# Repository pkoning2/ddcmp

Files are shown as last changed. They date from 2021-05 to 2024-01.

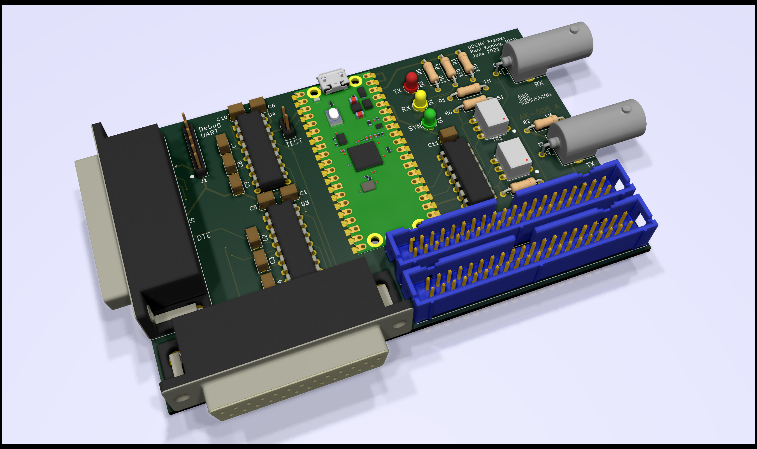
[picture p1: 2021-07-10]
kicad/ddcmp/ddcmp.png

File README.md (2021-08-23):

# DDCMP Framer

This is a DDCMP synchronous link framer, connected to a host with a USB interface.

## Documentation

For detailed documentation, look in the `doc` subdirectory:

1. `api.md` -- programming interface for the framer.
2. `kicad.md` -- instructions for assembling the circuit board.
3. `software.md` -- how to build and load the firmware.
4. `design.md` -- design notes.

## Connections

To use the framer, connect the micro-USB board to a USB port on the computer that will control the framer.

There are a number of choices for connecting the synchronous link to whatever device you want to use it with:

1. To use a synchronous modem or modem eliminator, connect it with a straight through DB-25 cable to the male DB-25 (marked "DTE"), and operate the framer in "rs232_dte" mode.

2. To connect to a DDCMP device such as the DMR-11 using an RS-232 connection, connect its male DB-25 connector with a straight through DB-25 cable to the female DB-25 (marked "DCE") on the framer, and operate the framer in "rs232_dce" mode.  In this mode the framer supplies the bit clocks; you specify the desiredd data rate as one of the start command parameters.

3. If you have a device such as a DMR-11 that has a line card which is meant to connect to a BC55 bulkhead panel via a 40-pin ribbon cable, but you don't have or do not want to use a bulkhead panel, connect the line unit with 40 pin ribbon cable to the 40-pin header J8 (marked "To LU").  You can use either RS-232 (with bit clock generated by the framer) or integral modem operation using this connection.

4. If you want to connect the framer to a BC55 bulkhead panel (RS-232 or integral modem), connect the BC55 with a 40-pin ribbon cable to the 40-pin header J7.  Do not install termination resistors on the integral modem panel (BC55A); for details, refer to `doc/kicad.md`.

5. You can connect integral modem coaxial cables to BNC connectors J2 (incoming data) and J3 (outgoing data).  Note that DEC specifies triax cable (two shields) but those connectors are expensive so here we just use BNC connectors, which should be fine so long as you're not operating in an extremely noisy environment.  Do not install terminating resistors at the framer end, they are built in to the board.

## Indicator lights

There are three indicator lights on the framer board, as well as an LED on the Raspberry Pico board itself.  They are:

1. Pico board LED: "on" indicator.  It lights up when the framer is started with a successful start command, and off when the framer is stopped.

2. "SYN" indicator: byte sync status.  This lights up when the framer receiver has completed byte synchronization, having received four or more consecutive SYN bytes (hex 96).  SYN status remains set unless the DDCMP state machine restarts sync search; it will do so if a header CRC error occurs.  If the light does not come on, this may indicate no received signal, or (for integral modem mode) speed mismatch exceeding the 10% receive rate tolerance.  If the SYN indicator flashes frequently, this may indicate poor signal quality, or (for integral modem mode) a speed mismatch right at the limit of what the device can handle.  Note that the weak signal capability of the integral modem depends on the transformers used; refer to `doc/kicad.md` for details.

3. "RX" indicator: flashes when a frame is received (either successfully or with an error).

4. "TX" indicator: flashes when a frame is transmitted.

The RX and TX LEDs have pulse stretchers, so the light flashes are clearly visible even at low packet rates.

The RX and TX LEDs flash once when a framer start command is successfully executed.

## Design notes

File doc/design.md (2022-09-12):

# Some design details of the DDCMP Framer

The framer takes advantage of a number of features provided by the Raspberry Pico RP2040 chip:

1. High speed programmable I/O state machine engines
2. Dual ARM core
3. USB support

For details, refer to the [RP2040 datasheet](https://datasheets.raspberrypi.org/rp2040/rp2040-datasheet.pdf "Data sheet").

# Receive processing

Synchronous DDCMP reception consists of a number of stages:

1. Demodulation (integral modem case)
2. Byte framing
3. Packet framing

## Demodulation

In the RS-232 DTE case, demodulation (which includes clock and bit data recovery) is done by the modem.  In the RS-232 DCE case, these steps do not really appear since the clock is generated locally and the bits appear as-is on the receive data pin.

For the integral modem, the framer does the demodulation of the FM modulated signal.  (For details, refer to the DMC11 Synchronous Line Unit Maintenance Manual, EK-DMCLU-TM-002.)   One of the PIO state machines handles clock and data recovery.  The approach is vaguely like the classic technique for UART receive; the state machine runs at 16x the nominal data rate, looking for the edge at the start of the bit cell.  It then waits for 3/4 of the bit time, and samples the input state.  If it is the same as at the start of the bit cell, that is a one bit, otherwise it is a zero bit.  The resulting data bit and a bit strobe signal (PIO IRQ signal) are generated by the demodulator state machine and will be used by the byte framing state machine.

## Byte framing

This consists of two stages: sync search, and data byte processing once in sync.  The input to the byte framing PIO state machine is the received data bit stream and clock.  The clock is an input pin for RS-232 DTE mode, the locally generated clock for RS-232 DCE mode, or the recovered bit clock for integral modem mode.

Initially the byte framing state machine is in sync search mode.  In that mode it shifts bits into a 32 bit register, and after each bit, compares the result against 4 SYN bytes (0x96969696).  Note that ideally it would be best to do a 16-bit compare against 2 SYN bytes, but the hardware does not support that and given that other DDCMP devices normally send around 8 SYN bytes before frames, requiring 4 for synchronization is acceptable.  When a match is seen, we have byte sync and the sync search mode is exited.  At this point the SYN LED is turned on.

When synchronized, the byte framing state machine continues to shift in bits to the input register, and every 32 bits pushes the result to the receive FIFO.  That FIFO is processed by the ARM (core 1), which will see properly framed bytes 4 at a time.

To go back to sync search state, for example to recover from a header CRC error or invalid start of header byte, the ARM core will force the byte framing state machine back to its starting address, which puts it back in sync search state.

## Packet framing

Packet framing is done in the ARM CPU since it is too complex for the PIO state machines.  Because of the real time requirements, core 1 is dedicated to this task; it runs in a tight loop receiving bytes 4 at a time from the byte framing PIO state machine through its receive FIFO.

The packet framer basically implements the DDCMP packet format recognition state machine seen in many other implementations of DDCMP.  It skips leading SYN bytes, then expects a valid start of frame byte (ENQ, SOH, or DLE) followed by 5 more header bytes and a correct 2 byte CRC-16 header CRC.  If the first non-SYN byte is not valid, the packet framer resets the byte framer state machine to sync search mode and goes back to looking for a valid frame start.

If the first byte is a valid start of frame, the framer examines the next entry in the receive buffer ring.  If it is in use, we have a no-buffers condition, which is counted as an error and sync search mode is entered to look for the next frame.  Otherwise, the framer begins to store arriving bytes into that buffer and accumulates the (header) CRC.  After 8 bytes, it verifies the CRC; if it is non-zero, the frame is completed with header CRC error status and sync search is entered.  

If the header CRC is good and the frame is a control frame (ENQ first byte), the buffer is completed as a good frame, and the framer goes back to look for the next frame.  Note that we do not do sync search in this case since the link is currently synchronized.  Other frame types are data; if so, the length field is extracted from the received header.  If it is invalid (zero or greater than 1488), this is counted as a length error and sync search is started.  Otherwise, the framer accumulates the next (length + 2) bytes, which are the frame payload and data CRC.

Once the data and data CRC have been received and buffered, the framer checks for zero CRC.  If so, the frame is marked as complete and good; otherwise, it is marked as commplete with data CRC error.  In either case, the framer goes back to look for another frame.  Unlike header CRC errors, data CRC errors do not trigger sync search.

# Transmit processing

Similar to receive processing, transmit processing for synchronous DDCMP consists of several parts:

1. Frame construction
2. Bit stream generation
3. Modulation

## Frame construction

The connected host supplies complete DDCMP frames to the framer except that the CRC fields are omitted.  The host request handler (in ARM CPU 0) copies the frame to be transmitted into the next transmit ring buffer, if free.  As part of the copy, the CRC is calculated and inserted after the header and, if applicable, the data.  After the end of frame a DEL byte (0xff) is inserted, this is as specified in the DDCMP spec to strengthen the CRC in case a bit is lost or inserted.

Frames are sent to the bit handling state machines using DMA, with the state machine FIFO is set to 8 bits wide.  Also, the transmit ring buffer contains 8 SYN bytes before the frame data area, which will be the sync pattern sent before each frame.  Currently there is no support for sending short sync sequences when permitted, that would only be an optimization and for many cases isn't all that interesting.  Nor is there support for abutting frames, which similarly is only an optimization and the rules are quite complex and involve DDCMP state information not known to the framer.

The transmit FIFO length is controlled by a conditional compile, TX8 which is on by default.  If off, 32 bit FIFO size is used and transmits are padded to 4 byte multiples.  Testing shows that this is not needed for supported speeds; we do see occasional CRC errors in BIST runs (due to FIFO underrun causing SYN bytes to be inserted in mid-packet) but only at 10 Mb/s.  All speeds that work for external connections, including non-standard extra fast speeds (2.5 or 5 Mb/s) work cleanly without underrun at 8 bit FIFO size.

Once the complete frame has been built, the buffer is marked as filled.  If DMA is not currently in progress, DMA of the new buffer is started by submitting its start address (address of the leading SYN sequence) and length to the DMA engine.  If DMA is in progress, this new buffer will be handled by the DMA completion interrupt handler when the DMA for the preceding buffer finishes.

## Bit stream generation and modulation

For RS-232 mode, the output bit stream is simply the sequence of bits (LSB first) from the transmitted packet.  The transmit handler for these modes picks up words from the output FIFO and shifts them a bit at a time to the transmit data pin.  For DTE mode, the shifting happens on the rising edge of the transmit clock input.  For DCE mode, the state machine runs at 4x the required data rate and it shifts output bits and generates the clock signal in a four-instruction loop.

For integral modem mode, the output signal is an FM modulated signal representing the bit stream, with an edge at the beginning of each bit cell and a second edge in the middle if the transmitted bit is a zero.  The PIO state machine program for this mode fetches 32-bit words from the FIFO, then shifts out one bit at a time and generates the correct waveform based on whether the bit is one or zero.  It runs at 4x the required data rate.  Note that for the integral modem case there is no connection between receive and transmit clocks, though the nominal values are expected to match.  The data rates can be set to different values, but this is only intended as a test tool to verify that the receive demodulation can handle bit clocks that are moderately (up to 10% is the DEC specification) out of tolerance.

# Modem control

The framer is designed for full duplex operation with very limited modem control.

In RS-232 using the DTE connection, DTR and RTS are set when the framer is turned on.  Modem control signals from the modem (DSR, CTS, RI, CD) are ignored.

In RS-232 using the DCE connection, DSR, CTS, and CD are set when the framer is turned on, and RI is off.  Modem control signals from the device (DTR, RTS) are ignored.

In integral modem mode, transmit carrier is sent as soon as the framer is turned on.  The line unit startup sequence is sent (see section 4.3.11.3 of the DMC-11 line unit maintenance manual), followed by the idle line state (SYN bytes) until the host starts sending DDCMP frames.

The RS-232 hardware does not support half-duplex or full modem control operation, mostly because the transceivers used don't have enough drivers and receivers to handle all the modem control pins explicitly.

The integral modem hardware has the transmit driver enable under firmware control, which means that it is probably possible to implement half duplex or multipoint operation, where the carrier has to be turned off when the station is not actively transmitting.  There is no support for this in the firmware, though.

# Host interface handling

The host interface uses the TinyUSB open source library, in device mode configured as an Ethernet device.  Some of the bits are adapted from the TinyUSB web server example, but note that the DDCMP Framer uses raw Ethernet, not IP.

The main loop, running in ARM CPU 0, polls the USB for outgoing Ethernet frames and the received packet ring (from CPU 1) for incoming DDCMP frames to be sent to the host.

The messages exchanged between host and framer are constructed as standard Ethernet frames, except that short frames are not padded (framer to host) or required to be padded (host to framer).  Refer to the API documentation in api.md for details on the encoding of the frames.

## Outbound frame processing (host to framer)

The framer checks the Ethernet protocol type field for the value 60-06 (the DEC reserved value for "customer use").  Frames with other protocol types are ignored.  Some will appear because operating services like DHCP or other configuration mechanisms may send IP frames on any interface that shows up.

If a framer type frame is seen, the first byte of the data is examined to see if it is a command or a frame to be transmitted.  Transmit frames are recognized by the fact that they start with one of the DDCMP frame start values EQN (005), SOH (201) or DLE (220).  Command use a DC1 (021) byte instead.  Any other first byte is an error.

Data frames are copied into a transmit buffer with CRC generated during the copy, then transmitted as described above.

Invalid requests including invalid transmits (such as bad frame lengths) are reported by the framer generating a status message to the host, in which the last_cmd_sts field is set to a non-zero value indicating the error.  Apart from that reporting, the request that encountered the error is ignored.

Commands have a command code in the second byte.  Defined commands are status request, off, on, and raw transmit.  Raw transmit is a test tool for diagnostics, it is not expected to be used in normal operation.  On and raw transmit requests have data following the command code, see the API document for details.

All commands except for a valid raw transmit generate a status reply.  Valid raw transmits are handled (the data is transmitted exactly as supplied, without any leading SYN, CRC handling, or trailing bytes added) with no status reply.

### "On" command

The command to start the framer includes additional data specifying the operating mode and data rate.  Refer to the API spec for details.

Command processing sets all the Pico pins to the proper operating setting, loads the appropriate programs into the PIO state machines, configures them, and starts them.  It also starts CPU 1 if that has not already been done (it is done only once per power up since CPU 1 can't be stopped after having been started).

Two of the PIO state machines control the receive and transmit activity LEDs, providing "pulse stretching" so the light flashes are bright enough to be visible if traffic is sporadic.  They flash once when started, so the execution of the "On" command will light the "active" LED (on the Pico board) and flash the RX and TX LEDs once.  The SYN LED will be off until a valid signal is received and byte sync is established.

## Inbound frame processing (framer to host)

In the main loop the framer looks for things to send to the host.  There are two cases: status, and received data.  Status takes precedence.

At any time when status needs to be reported, the `send_status` flag is set.  If it seen set in the main loop, the status buffer is sent to the host and the flag cleared.

Otherwise, if the next buffer in the receive ring is not free, it is sent to the host and marked free.

The first two bytes in all inbound frames are the receive status, which is 0 for good frames and non-zero for various error cases such as header CRC error.  (Refer to the API spec for details.)  Status frames always have 0 receive status.

# BIST

Built-in self test is intended mostly as a simple test to verify a newly built framer is working correctly.  In BIST mode, the framer continuously transmits 500 byte frames (MOP mode frames) containing an incrementing sequence number followed by a mixed data pattern.  Any received frames are counted but otherwise ignored.  Transmit requests from the host are silently ignored, but status requests and stop command are honored.  Every 1000 transmits, a status message is generated.

There are two ways to invoke BIST:

## Power up BIST

If GPIO pin 2 is grounded at framer power up (for example, by installing a jumper on 2-pin header J4, labeled "TEST"), this forces BIST, integral modem, internal loopback, 1 Mbps.  The USB interface is still active in this mode so the host can monitor BIST progress from the periodic status frames, and can stop the test by sending an Off command.

## BIST mode in Framer On commands

The host can request BIST mode as part of an "On" command.  This allows BIST mode to be run (i.e., the traffic generator and receive packet ignore functions) with other operating modes such as RS-232 and external loopback, or no loopback at all.  Several of the tests in the framer test suite in PyDECnet use this option.

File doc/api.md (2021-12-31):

# DDCMP Framer application interface specification

The framer appears to the host as an Ethernet interface.  The interface hardware address starts with aa-00-03 (an unused OUI once assigned to DEC and then rendered obsolete by IEEE 802 -- see `ether-i.pdf`).  The next 23 bits of the interface address are random, derived from the Raspberry Pico unique board ID, and the low order bit is 0 so the interface address is even.  The framer appears as an Ethernet device attached to that interface; its address is one larger than the interface address. 

Communication with the framer uses raw Ethenet packets with protocol type is 60-06 (DEC protocol type assigned to "Customer use").  Following the protocol type is a payload length field, 2 bytes little endian, following the common pattern of many Digital protocols (like DECnet).  This allows the frames to be padded to the minimum Ethernet size; USB does not require this but SIMH does.  Note that padding has a clearly visible performance impact for some workloads (lots of small frames arriving quickly); if this is an issue you may want to experiment with having it turned off.  Note that the framer does not examine the Ethernet address fields of message sent to it; so long as the protocol type is 60-06, it will process the frame.  

The payload of these Ethernet packets is either a DDCMP frame, or a command/status packet.  The encoding is slightly different for inbound (received data to host) vs. outbound (transmitted data from host).

Outbound payloads are simply DDCMP frames as encoded on the wire, except that the CRC values are generated by the framer.  The CRC at the end may simply be omitted (so a DDCMP control frame need only be 6 bytes).  The header CRC field of data frames is present but not used, so the data begins the usual 8 bytes after the start of the frame.  The framer supplies header and (if applicable) data CRC fields, as well as leading SYN and trailing DEL bytes.  

Inbound payloads begin with a 2-byte receive status value, followed by the received DDCMP frame exactly as received, including the CRC fields.  Note that the framer implements CRC checking; the host normally would not look at the CRC bytes but simply use the status value to learn whether the packet is good or bad.

In either direction, we pad frames to the minimum frame length of Ethernet.  USB emulated Ethernet NIC does not appear to object to undersized frames, but some applications (like SIMH) assume that the Ethernet minimum should be enforced.  Since we limit framer packets to standard Ethernet size, the largest DDCMP data length supported is 1486.

Command/status packets begin with 021 (DC1) which is not a DDCMP frame start value.  Outbound they carry commands to the adapter; inbound they carry status and counters.  Note that the inbound status packet is preceded by a receive status word, as always; for status packets the receive status is always zero (OK).

Receive status word values:

0: good frame

1: Header CRC error

2: Data CRC error

3: Frame too long (if so, the entire data field is absent)

4: Loss of carrier or bit clock in the middle of a frame (the buffer will contain the portion of the frame that was received)

Command packets start with 021.  The next byte is the command:

0: status request

1: start

2: stop

3: send raw data

Status, start, and stop commands produce a status packet in reply (the status request simply is a "no state change" command).  "Send raw data" commands do not for valid requests, but if the command is rejected for any reason a status is generated to show this. For "send raw data", the data to be sent is the remainder of the command packet, starting immediately ater the command byte.  

For start, configuration settings follow:

Mode and flag bits (2 bytes).  Mode is the bottom 2 bits:

0: RS-232 DTE mode (bit clocks supplied by the connected modem)

1: Integral modem

2: RS-232 DCE mode (bit clock generated by framer)

Flags:

Bit 2: Internal loopback.  If mode is supplied as 0, it is forced to 2.

Bit 3: Built-in selftest.  In this mode, transmit requests are ignored and
received data is counted but not delivered.  The framer internally
generates a stream of DDCMP messages (500 bytes long) to exercise the
transmit and receive data paths.  Status requests still work so
progress can be monitored via status requests, and a stop command will
terminate the test.

Bit 4: Split speed.  This applies only to the integral modem case.  If set, the transmit speed is taken from the txspeed field rather than the speed field.  This is a test function that allows verifying the correct operation of receive data recovery when the sending end data rate is out of spec.

Bit 5: DMC mode (DDCMP V3.03).  Modifies the frame generation rules to match what the DMC11 needs.  See the DMC11 Microprocessor manual, appendix I, for details.

Bit 6: Raw waveform mode.  Valid with integral modem only.  In this mode, the modulator part of the integral modem handling is bypassed.  Only the "raw transmit" command can be be used; regular transmit is rejected.  Cannot be combined with BIST mode.  The raw transmit buffer is interpreted as one bit per modulation time slot (two bits per data element) directly representing the waveform to be transmitted.  This is a test mode, intended for verifying receive clock/data recovery and the handling of loss of carrier.  See the "test_framer" test suite for examples.

Speed: (4 bytes):

This specifies the bit rate in bits per second.  For RS-232 DCE mode, it is the frequency of the receive and transmit clock signals.  For integral modem, it is the transmit speed and the nominal receive speed; actual receive clocking is from the incoming data, which must match the specified rate +/- 6%.  Speed is not applicable for RS-232 DTE mode, in which the bit clocking is entirely under control of the modem.  Note that RS-232 is not officially specified for high speeds; it works well at 56 kbps with short cables, and can probably be made to work at 250 kbps, but it is unlikely to run at 1 Mbps since the required rise/fall times are too slow for that.  Standard integral modem speeds go as high as 1 Mbps; the adapter can go faster but standard DEC hardware does not; also, at some higher speeds the quantization error of the PIO clock divider becomes a problem and receive data recovery no longer works.

Transmit speed (4 bytes):

This is the transmit data rate, if the "split speed" bit is set in `mflags`.

Status packet starts with 021 (after the usual 2 byte payload length and receive status fields), followed by state and counter data:

* state (1 byte): flags, bit 0 = on (active), bit 1 = in-sync, bit 2 = bit clock ok
* mode and flags (2 bytes): as described above for the Start command
* maximum frame payload: 1486 -- information for the host software
* speed (4 bytes): as described above.  Not used for RS-232 DTE mode.
* transmit speed (4 bytes): as described above.  
* Counters -- all are 4 bytes and wrap on overflow:
* received good frames
* transmitted frames
* received good bytes
* transmitted bytes
* header crc errors
* data crc errors
* frame too long errors
* buffer unavailable errors
* Additional status:
* last command status (4 bytes), 0 for good, non-zero for various errors
* measured data rate (4 bytes), in bits per second
* framer firmware version (null-terminated ASCII string)

Status messages are generated:
1. At device powerup.
2. In response to any command.
3. In response to a transmit or raw-transmit request that has invalid parameters.
4. When the in-sync status changes (sync acquired or sync lost).
5. In BIST mode, after every 1000 transmitted frames.

Note that the measured data rate for the integral modem case is an approximation since it operates by measuring the edge timing of the received waveform.  The calculation assumes that the received data is half ones and half zeroes, which is the case for an idle line (SYN bytes are half and half).  If the line is actively carrying data and that data has a different bit density the measured line rate will be inaccurate; in particular for all zeroes it will be 33% higher than the true value.  The intent of this data item is to allow checking the data rate of a connected device whose clock may be off spec or unknown, allowing the framer to be configured with a matching data rate for reliable operation.

Last command status values are:

0: OK (command accepted)

1: Command message too short (must be at least 2 bytes for status or stop, at least 8 bytes for start).

2: Unrecognized command code (byte after the 0x11 command marker)

3: Start command issued when the device is already started

4: Speed out of range.  Supported speeds are 500 to 1,000,000 bits per second.

5: Bad transmit length.  For regular transmits, this means a control frame (starts with 0x05) less than 6 bytes long, or a data frame (starts with 0x81 or 0x90) with length in the header either 0 or greater than 1486, or not enough data in the Ethernet packet for the length given in the header.  For raw transmit, more than 1486 bytes.

6: Transmit request when the framer is stopped.

7: Invalid combination of mode bits in start command: RAW_WAVEFORM mode used with RS232 or BIST.

8: (Regular) transmit request while RAW_WAVEFORM mode is in effect.

Note that transmit attempts in BIST mode are not errors; they are simply ignored.

## Diagnostics

### Built-in self test

If the framer is powered up with a jumper installed on J4 (marked "TEST"), it enters BIST mode in integral modem mode, internal loopback, 1 Mb/s.  Note that internal loopback of any kind is not dependent on the transceiver hardware, so it works even if the corresponding external connection option is not installed on the board.  In BIST mode the device continuously sends 500 byte test data frames, which are received and counted but not otherwise processed.  Every 1000 transmitted frames a status message is generated and sent to the host, which can be used to monitor the progress of the BIST.  BIST mode continues until the framer is powered down or until a "stop" command is issued.

BIST mode can also requested by setting bit 3 in the mode/flags field of a "Start" command.  In this case, the operating mode and loopback or not are selected by the other bits in the field.  So, for example, if a loopback connector is installed on the RS-232 DCE connector, a test including the RS-232 transceivers can be done by requesting RS-232 DCE mode, a suitable speed (250,000 should work) and BIST.

## Device validation and diagnostic test suite

The DECnet/Python package, in the `tests` directory, contains a set of framer tests in `test_framer.py`.  These can be invoked in the usual way, either the full set or any desired specific tests or test classes.  Refer to the Python library manual, "unittest" module, for details.  Some of the tests require loopback connectors to be installed, and some that use RS-232 DTE mode also require a clock source such as a modem eliminator to be attached to the DTE connector.  If this is not done those tests will fail with messages indicating the reason is a missing loopback connector or clock source.

The full set of framer tests require about 3.5 minutes to run.

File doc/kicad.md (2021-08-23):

# DDCMP Framer

The `kicad/ddcmp` subdirectory contains the design files for the DDCMP framer circuit board (AK-005 A), which you can inspect or modify using the open source KiCAD package.

## Creating the circuit board

There are three ways to get a circuit board.
1. From the shared designs section of the OSHPark PCB fabricator website, in [this link](https://oshpark.com/shared_projects/buAWT8Hy "DDCMP Framer").
2. From any PCB fabricator that accepts KiCAD board files (such as OSHPark).
3. From any PCB fabricator that doesn't, by generating the standard *Gerber* files.

If you want to use a fabricator that needs Gerber files, open the `ddcmp.kicad_pcb` file using KiCAD (specifically the *Pcbnew* application) and use the File->Plot menu option to generate them.  You'll want to review the detailed instructions from the fabricator to confirm settings, file name rules, etc.

## Schematic

The board schematic is in `ddcmp.sch` (which is the top level of a hierarchical design pointing to three additional `*.sch` files).  You won't need this to create the board, but you can review this if you are interested, or if you want to modify the design.

## Assembly

The design is a simple circuit board; nearly all components are through-hole.  The one exception is the pair of Min-Circuits transformers, which are surface mount, but with 0.1 inch lead pitch so they do not create any problem.  If you have experience building small electronic kits it should not create any problems.  If you do not, you may want to seek out some help since this is not a "Heathkit" style kit with detailed instructions or tutorials.

## Parts list

Here are all the parts in the design, with schematic reference (also on the board silk screen labeling), value or device type, description, along with manufacturer name and Digikey part number.  The Digikey numbers are just by way of illustration.  Capacitors and resistors are generic, you can replace them by similar devices from other suppliers so long as they fit in the available space.  The capacitors  are small ceramic devices with 0.1 inch lead spacing; the resistors are standard 1/4 watt parts. 

| Ref | Value | Description | Manufacturer | Digikey part # |
| --- | ----- | --- | --- | --- |
| C1 | 0.1uF | Ceramic capacitor | Kemet | 399-14010-1-ND |
| C2 | 0.1uF | Ceramic capacitor | Kemet | 399-14010-1-ND |
| C3 | 0.1uF | Ceramic capacitor | Kemet | 399-14010-1-ND |
| C4 | 0.1uF | Ceramic capacitor | Kemet | 399-14010-1-ND |
| C5 | 0.1uF | Ceramic capacitor | Kemet | 399-14010-1-ND |
| C6 | 0.1uF | Ceramic capacitor | Kemet | 399-14010-1-ND |
| C7 | 0.1uF | Ceramic capacitor | Kemet | 399-14010-1-ND |
| C8 | 0.1uF | Ceramic capacitor | Kemet | 399-14010-1-ND |
| C9 | 0.1uF | Ceramic capacitor | Kemet | 399-14010-1-ND |
| C10 | 0.1uF | Ceramic capacitor | Kemet | 399-14010-1-ND |
| C11 | 0.1uF | Ceramic capacitor | Kemet | 399-14010-1-ND |
| D1 | SYN | 3 mm green LED | SunLED | 1497-1490-ND |
| D2 | RX | 3 mm yellow LED | SunLED | 1497-1492-ND |
| D3 | TX | 3 mm red LED | SunLED | 1497-1491-ND |
| J1 | UART | 6-pin header | Harwin Inc. | 952-2269-ND |
| J2 | RX | BNC connector | Molex | WM20430-ND |
| J3 | TX | BNC connector | Molex | WM20430-ND |
| J4 | TEST | 2-pin header | Harwin Inc. | 952-2261-ND |
| J5 | DTE | DB25 male connector | Amphenol ICC | L717SDB25P1ACH4F-ND |
| J6 | DCE | DB25 female connector | Amphenol ICC | L77SDB25S1ACH3R-ND |
| J7 | To BC55 | "Berg" 40 pin connector | Amphenol ICC | 609-1779-ND |
| J8 | To LU | "Berg" 40 pin connector | Amphenol ICC | 609-1779-ND |
| R1 | 1M | Carbon film resistor | Yageo | 1.0MQBK-ND |
| R2 | 1M | Carbon film resistor | Yageo | 1.0MQBK-ND |
| R3 | 150 | Carbon film resistor | Yageo | 150QBK-ND |
| R4 | 150 | Carbon film resistor | Yageo | 150QBK-ND |
| R5 | 150 | Carbon film resistor | Yageo | 150QBK-ND |
| R6 | 51 | Carbon film resistor | Yageo | 51QBK-ND |
| R7 | 51 | Carbon film resistor | Yageo | 51QBK-ND |
| TR1 | TT1-6-X65+ | Transformer | Mini-Circuits |  |
| TR2 | TT1-6-X65+ | Transformer | Mini-Circuits |  |
| U1 | Pico | Raspberry Pico | Raspberry Pi | 2648-SC0915CT-ND  |
| U2 | max3491ecpd | RS-422 transceiver | Maxim | MAX3491CPD+-ND |
| U3 | MAX3222 | RS-232 transceiver | Maxim | MAX3222ECPN+-ND |
| U4 | MAX3222 | RS-232 transceiver | Maxim | MAX3222ECPN+-ND |

If you want to use Digikey as your supplier, the saved BOM is available [there](https://www.digikey.com/short/h1mqd0dm "Digikey BOM").  Note that TR1 and TR2 are not in that BOM since Digikey does not have these; you can order them directly from Mini-Circuits.

### Optional components

Apart from U1 (the processor) almost all the parts are optional; install them or not depending on which features you are interested in.  When in doubt, consult the schematic to see what each part does.

The options are:

1. RS-232 support: C1-C10, J4, J5, U3, U4.
2. RS-232 DTE support: J5.
3. RS-232 DCE support: J4.
4. Activity lights: omit D1, D2, and/or D3 with their associated resistors R3, R4, and/or R5 if you do not want the SYN, RX, and/or TX indicators.
5. Integral modem support: C11, J2, J3, R1, R2, R6, R7, TR1, TR2, U2.
6. Integral modem direct coax connection: J2, J3.
7. DEC BC55 bulkhead connection support: J7.
8. Connection to DMR/DMP/DMV line unit, or DMC RS-232 line unit: J8.
9. Debug UART connection: J1.
10. Easy access to built-in selftest feature: J4.

The BOM and schematic shows a green LED for the SYN indicator, yellow for RX, and red for TX.  You can use other combinations of red, yellow, and/or green if you prefer.  Note that blue or white LEDs have too high a forward voltage drop to be used here since the output pins are 3 volt outputs.

### Transformer alternatives

The listed part for TR1 and TR2 is the Mini-Circuits TT1-6-X65, which is a 6 pin DIP (through-hole) part.  It doesn't appear in the Digikey catalog, but it can be obtained directly from Mini-Circuits.

If you have trouble getting this part, several other Mini-Circuits transformers could be used instead.  The alternatives are all surface mount parts; the PCB footprint is designed to handle either the surface mount or the DIP part.

#### Tested alternatives

1. Mini-Circuits ADT1-6T+ (Digikey 3157-ADT1-6T+CT-ND).  This one has a specified lower limit of 30 kHz, which means 56kbps is slightly out of spec.  Loopback test over around 70 feet of small size coax with a number of connectors shows no errors, but the eye pattern is just barely open enough for that to be true.  Higher speeds work fine and have excellent eye patterns.  If you intend to use short cables, or high speeds (250 kbps or above), this option is fine.

#### Untested alternatives

1. Mini-Circuits ADTT1-6+ (Digikey 3157-ADTT1-6+CT-ND) appears to be suitable judging by its specifications.  Its low frequency limit is 15 kHz which indicates it should have more margin than the ADT1-6T+ at 56 kbps.

2. Mini-Circuits ADT2-71T+ (Digikey 3157-ADT2-71T+CT-ND) may work.  This is a 1:2 impedance transformer.  The MAX3491 transceiver is designed for either 50 ohm or 100 ohm load so this should be fine, but the output voltage at the 50 ohm connector will be somewhat reduced.  So long as the cables are not too long I would not expect a problem.  If this option is used, replace R6 and R7 by 100 ohm resistors.  Also, with this part the correct orientation is important -- the dot on the case needs to go where it is marked on the board.

### Integral modem terminations

The framers has on-board 51 ohm termination resistors for the integral modem connections.  If you use a BC55A integral modem bulkhead panel, do not install termination resistors on the panel, or, if you want to use those terminations, omit R6 and R7 from the framer.

If you want to use the framer in a multipoint configuration, you need to omit the on-board terminations and use cable termination (at the endpoints) instead.  Note that the framer firmware does not currently support multipoint operation, but it is probably possible to create firmware that does with the existing board; I have not studied this in detail.

If you use the line unit 40-pin connection (J8) with the integral modem, you will only have a single termination on each connection rather than two, which may affect the signal integrity at low speeds.  If you get CRC errors at 56 kbps, replace R6 and R7 by 22 or 24 ohm resistors.

### Assembly suggestions

I found that this order of installing the components works well:
1. U1 (Raspberry Pico).  You can surface-mount this or use pin headers (or even short wires) if you prefer.  There are mounting holes to secure the part to the board, which is probably a good idea if surface mounted so the mechanical integrity doesn't depend on the shear strength of the solder joints.  The mounting holes are for M2 (metric 2 millimeter) screws.  #2 US screws are a hair too big.
2. TR1, TR2 transformers, if you are using surface mount parts
3. Resistors and capacitors
4. LEDs
5. U2, U3, U4 DIP integrated circuits; also TR1 and TR2, if through-hole
6. J1, J4 pin headers
7. J2, J3, J5, J6, J7, J8 connectors.

Note the correct orientation of D1, D2, D3, J7, J8, U1, U2, U3, and U4.  U1 is oriented with the USB at the top of the board and all the contacts matched to pads on the board.  The other three ICs have a square pad at pin 1.  J7 (the 40-pin connector) has the keying notches towards the top of the board.  The LEDs have their flat side at the square pad.

The transformers TR1 and TR2 have an orientation dot on the package.  For the ADT2-71T+ orintation is important (see above).

The coax connectors (J2 and J3) are made of zinc alloy (pot metal).  This is unfortunately standard practice for PCB mount BNC connectors.  Before installing, lightly sand the thick body pins to make the solder stick better.  It will take a fair amount of heat to solder these pins; use an adequate soldering iron and beware of burning your fingers on the connector bodies for several minutes afterwards.

## Software load

After the board is built you will need to load the software.  See the `software.md` file for instructions.

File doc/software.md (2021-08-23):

# DDCMP Framer software

The `firmware` subdirectory contains the software for the DDCMP framer.

## Loading the software

Plug a micro-USB to USB cable into the Raspberry Pico USB connector (at the top edge of the board) and plug the other end into a suitable PC or Mac.  You should see a file system (removable storage device) appear named `RPI-RP2`.  If you are reprogramming an already programmed board, rather than doing the initial load onto a board newly delivered from the factory, you will need to hold down the pushbutton on the Raspberry Pico board while you're connecting it to the PC, this forces the boot ROM to enter software load mode.

Copy, by drag and drop or a suitable shell command, the file `ddcmp.uf2` to that file system.  The code will be written into on-board flash and will start.  This results in the abrupt disappearance of the `RPI-RP2` file system; your PC may object to this and display some sort of warning message.  Ignore that message.

## DDCMP Framer operation

When running, the framer will appear as an Ethernet device, in whatever way your host machine operating system handles this.  You can recognize it by the fact that its MAC address is always aa:00:03:04:05:06.  It should appear within a few seconds after you plug in the framer.  When it does, the device is ready for use.

You will need to communicate with the framer using Ethernet packets to tell it what to do.  Sufficiently recent versions of DECnet/Python (pydecnet) and SIMH (TBD) can do this; refer to the documentation that comes with these packages.  You can also write your own controlling software, using the information in file `api.md`.

### Self-test

If J4 is installed, you can access an internal self-test feature by installing a jumper on that header before connecting the board to power.  This will set internal loopback mode at 1 Mb/s and a test packet generator that sends 500  byte packets continuously.  Normal operation is shown by all three LEDs lighting up solid.  Every 1000 packets the self-test will send a status API message to the connected host; you can use host software to receive and display these, or capture them with a tool such as tcpdump or wireshark.  To terminate the test, simply unplug the USB cable and remove the jumper.

## Building the software

A pre-built binary `ddcmp.uf2` is supplied on Github.  You can build your own, modified if desired.  Install the Raspberry Pico SDK using the instructions given in [Getting started with Raspberry Pi Pico](https://datasheets.raspberrypi.org/pico/getting-started-with-pico.pdf "Getting started document").  Be sure to set environment variable `PICO_SDK_PATH` to the root directory of the SDK.  You will also need the `cmake` tool.

With the SDK installed, go to the `firmware` directory and execute:

    cmake .
    make

This will build all the necessary components and produce a loadable binary, `ddcmp.uf2`.  Load it into the board using the instructions given above.

## Options

There is only one significant build option: change `#define DEBUG 0` to `#define DEBUG 1` to enable debug output to the UART.  Plug in a 3.3 volt UART at J1 (note the orientation: pin 1, black wire, is marked by a dot).  The UART is set for 115,200 baud, 8 bits, no parity.  Debug messages appear in the source code as DPRINTF statements.  You can define DEBUG to be 2, this also enables the detailed debug messages (DDPRINTF), but that is very verbose and will significantly slow down operation of the device.

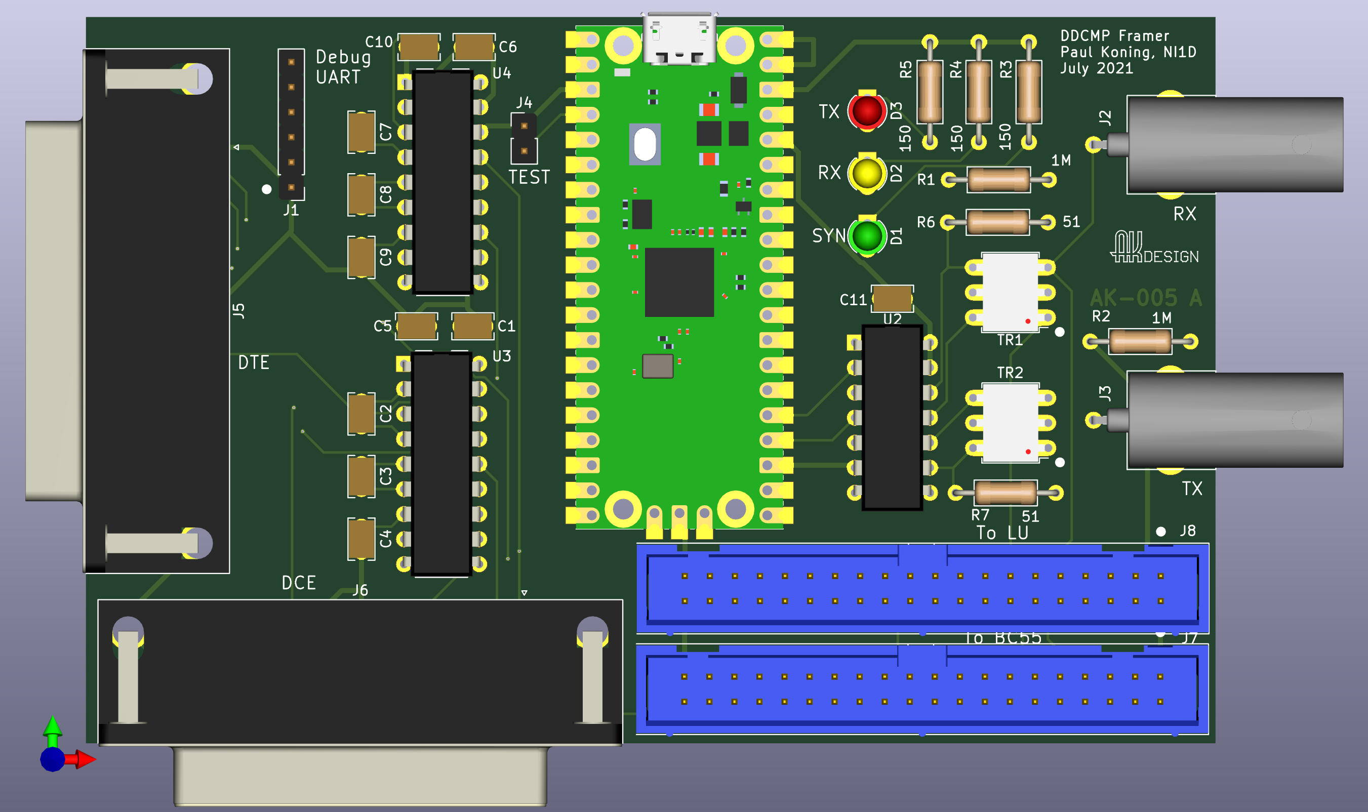
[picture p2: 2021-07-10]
kicad/ddcmp/ddcmp-top.png

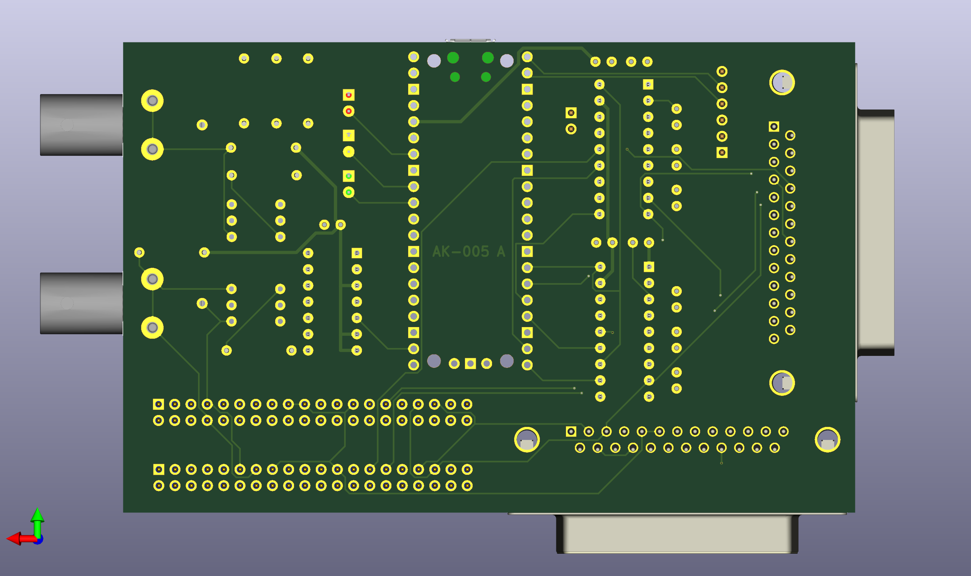
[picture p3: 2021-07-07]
kicad/ddcmp/ddcmp-bottom.png

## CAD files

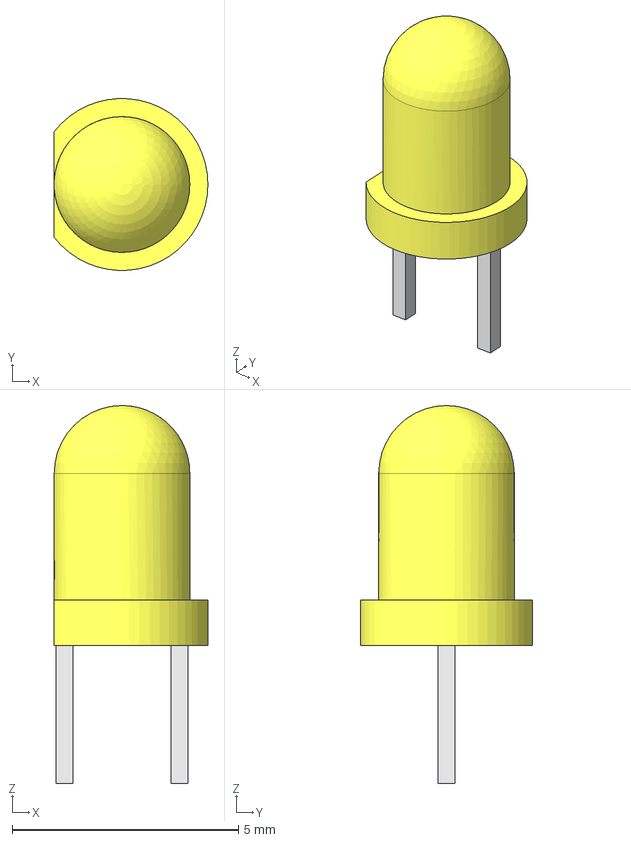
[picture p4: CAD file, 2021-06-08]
kicad/ddcmp/ddcmp_parts/LED_D3.0mm_yellow.step
3.40 x 3.80 x 8.35 mm
LED_body
Lead_1
Lead_2

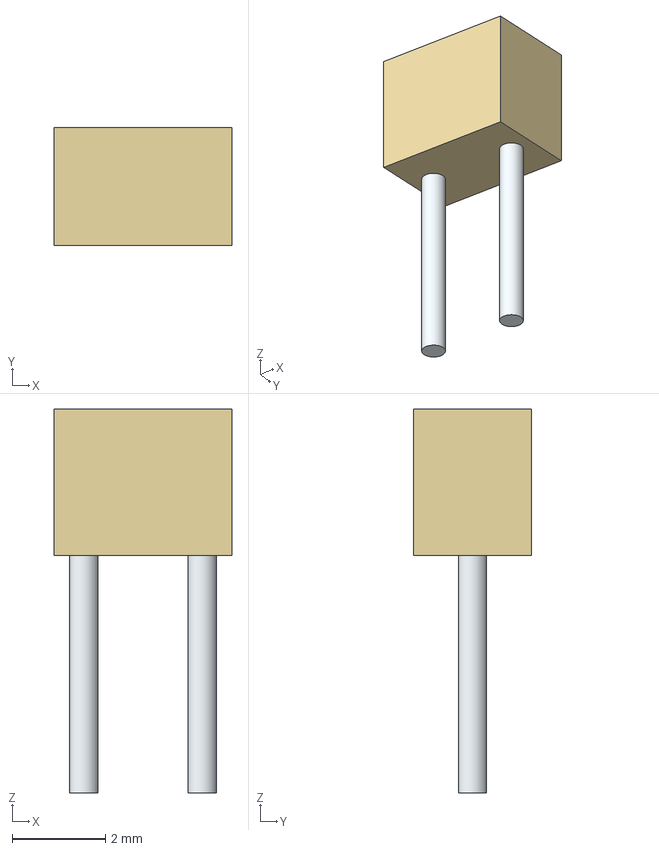
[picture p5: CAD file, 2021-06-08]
kicad/ddcmp/ddcmp_parts/kemet_cap.step
3.81 x 2.54 x 8.24 mm
Leads x 2

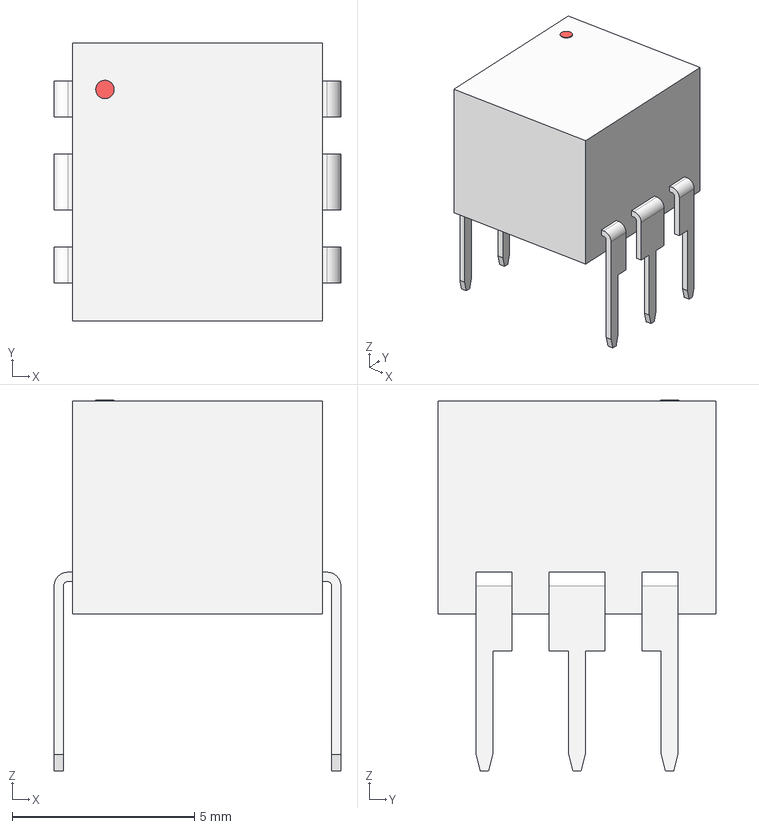
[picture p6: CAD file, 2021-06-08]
kicad/ddcmp/ddcmp_parts/X65.step
7.87 x 7.62 x 10.2 mm
Pins

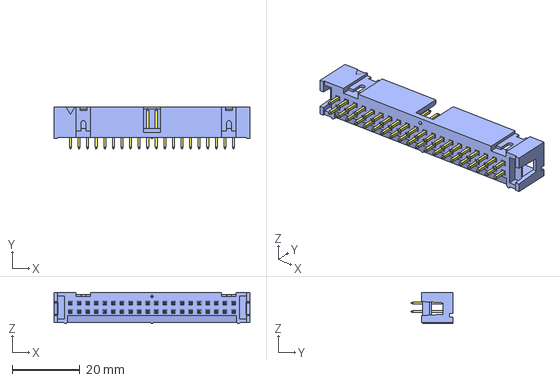
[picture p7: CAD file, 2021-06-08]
kicad/ddcmp/ddcmp_parts/BERG_blue_40pin.step
58.0 x 12.4 x 9.27 mm
71965_Y40
71953-Y01 x 40

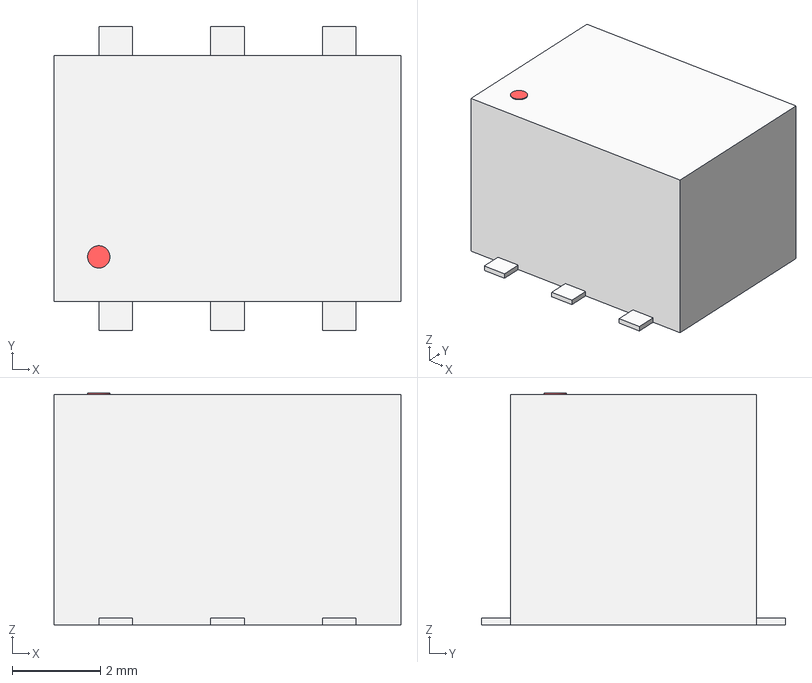
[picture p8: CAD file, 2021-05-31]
kicad/ddcmp/ddcmp_parts/CD637.step
7.87 x 6.91 x 5.26 mm

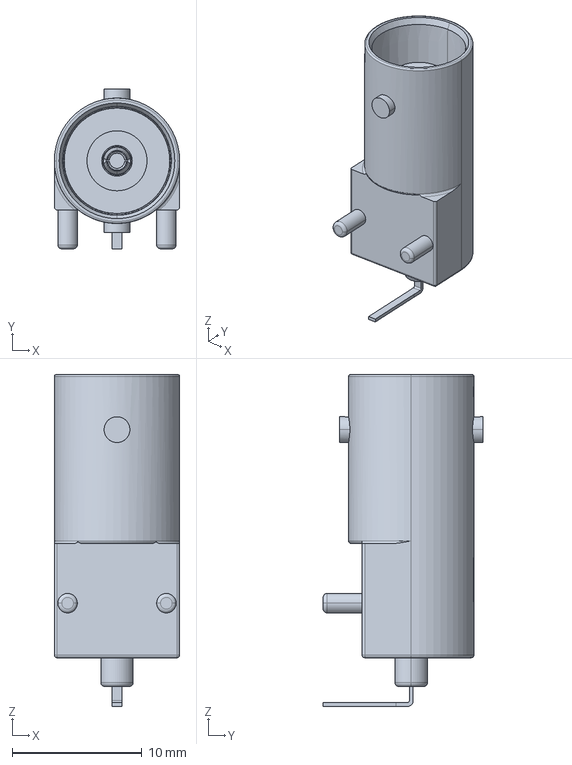
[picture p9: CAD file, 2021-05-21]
kicad/ddcmp/ddcmp_parts/731000105.step
9.65 x 12.3 x 25.6 mm

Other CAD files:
kicad/ddcmp/ddcmp_parts/LED_D3.0mm_red.step
kicad/ddcmp/ddcmp_parts/LED_D3.0mm_green.step
kicad/ddcmp/ddcmp_parts/75869_y07_asm.step

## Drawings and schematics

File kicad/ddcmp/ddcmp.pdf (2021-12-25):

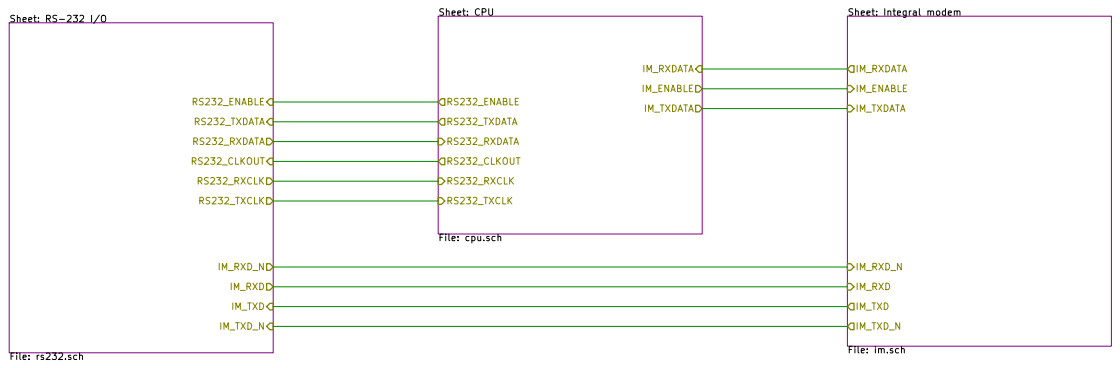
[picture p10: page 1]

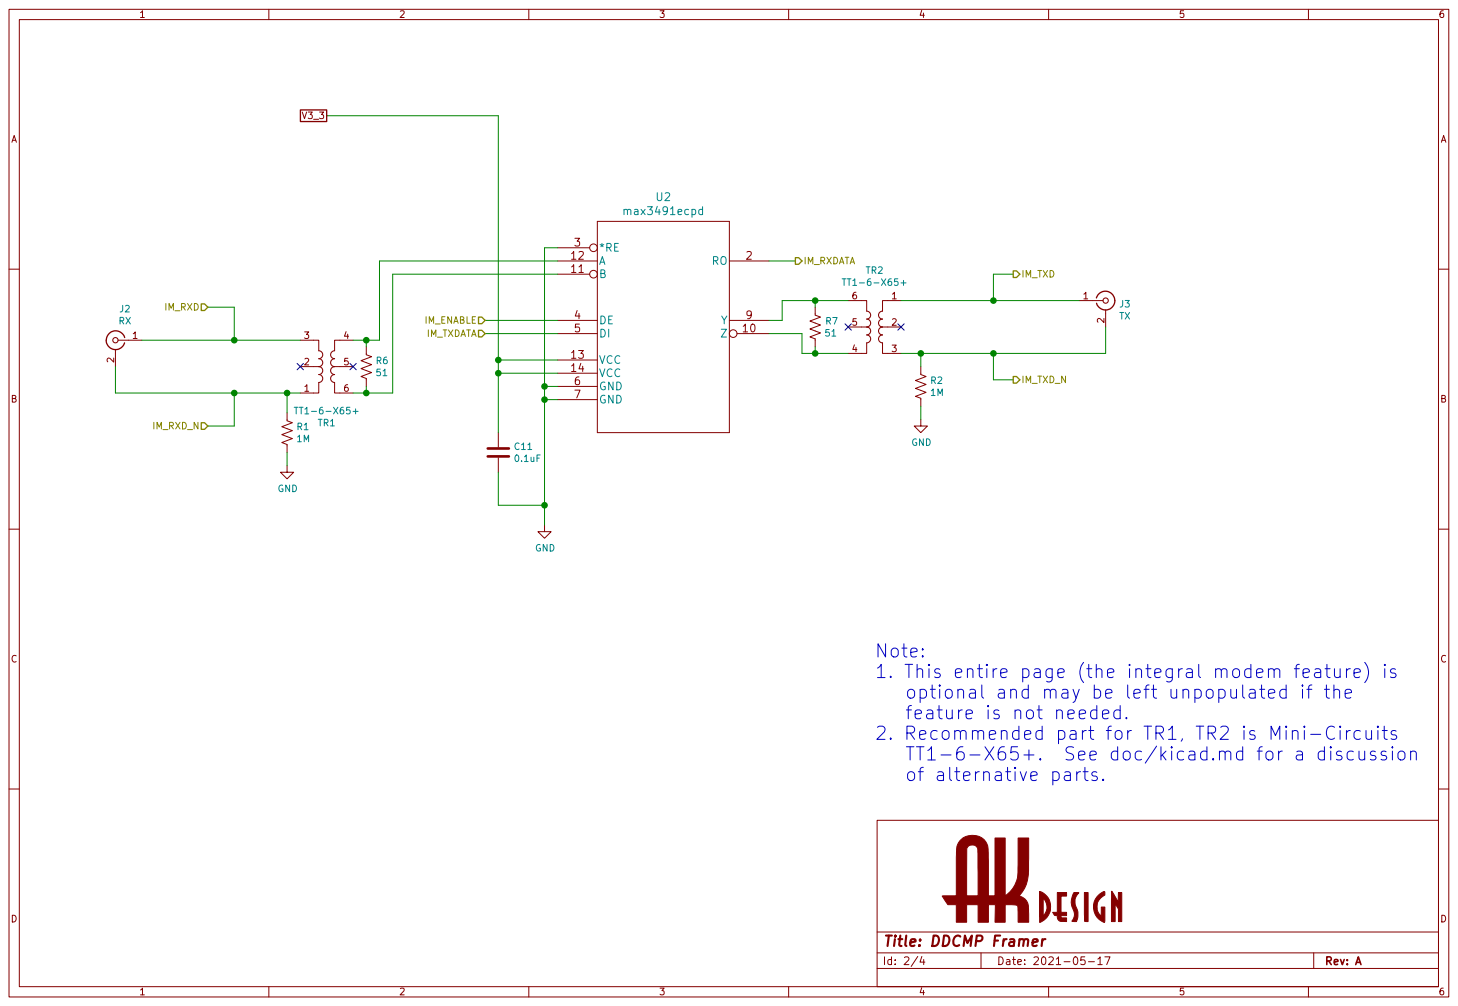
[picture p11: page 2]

1. This entire page (the integral modem feature) is
optional and may be left unpopulated if the
feature is not needed.
2. Recommended part for TR1, TR2 is Mini-Circuits
TT1-6-X65+. See doc/kicad.md for a discussion
of alternative parts.

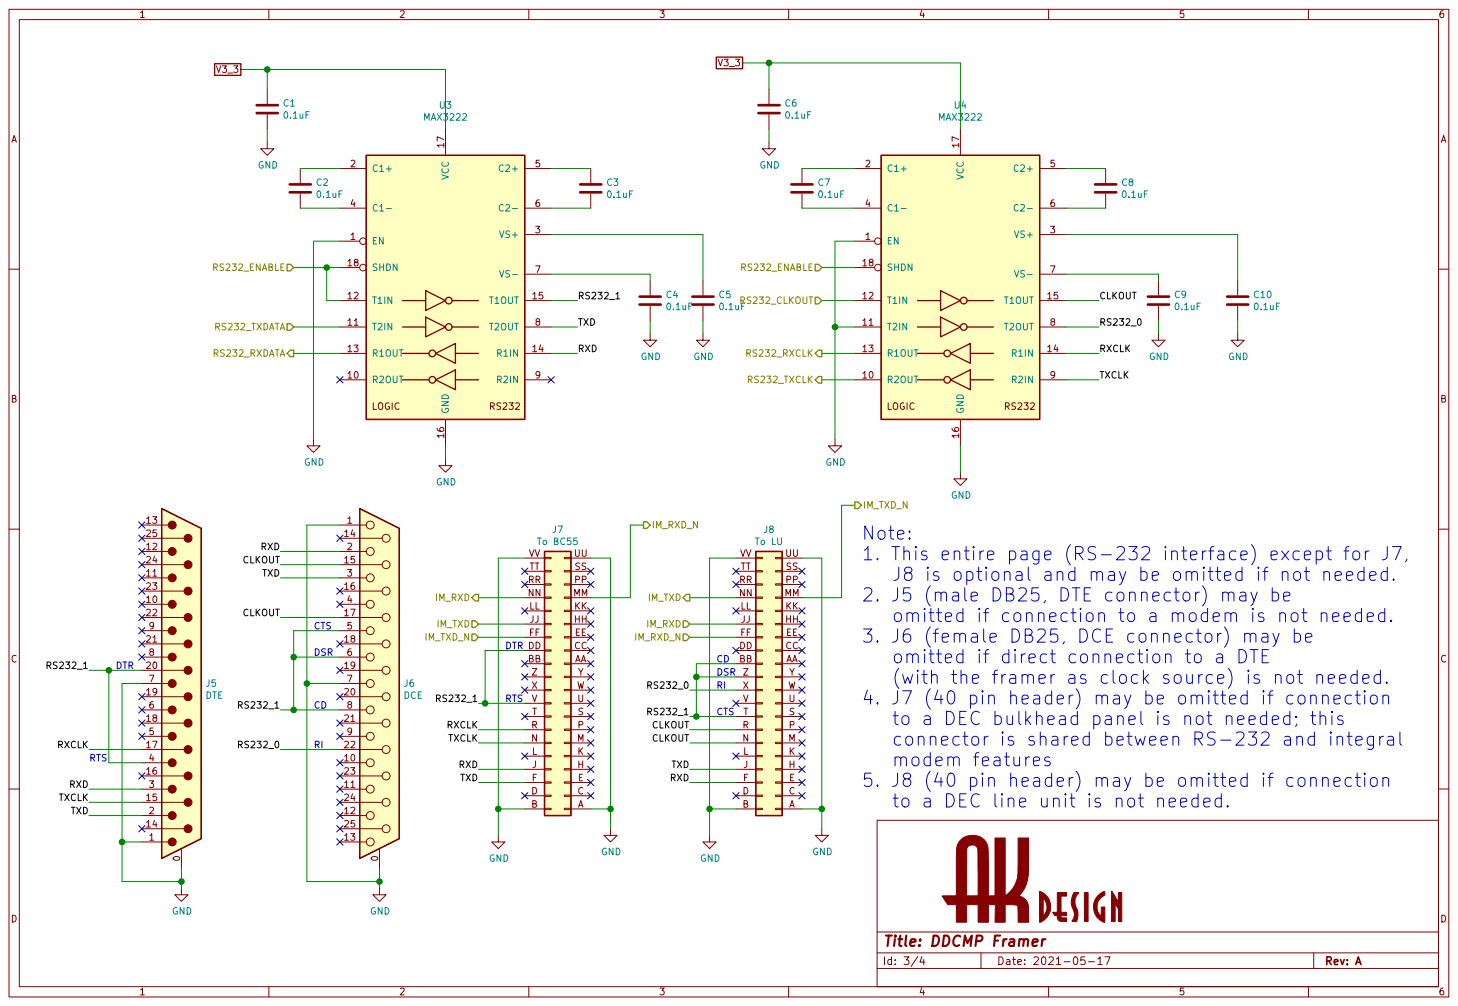
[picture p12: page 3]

1. This entire page (RS-232 interface) except for J7,
J8 is optional and may be omitted if not needed.
2. J5 (male DB25, DTE connector) may be
omitted if connection to a modem is not needed.
3. J6 (female DB25, DCE connector) may be
omitted if direct connection to a DTE
(with the framer as clock source) is not needed.
4. J7 (40 pin header) may be omitted if connection
to a DEC bulkhead panel is not needed; this
connector is shared between RS-232 and integral
modem features
5. J8 (40 pin header) may be omitted if connection

to a DEC line unit is not needed. CD
RI DSR

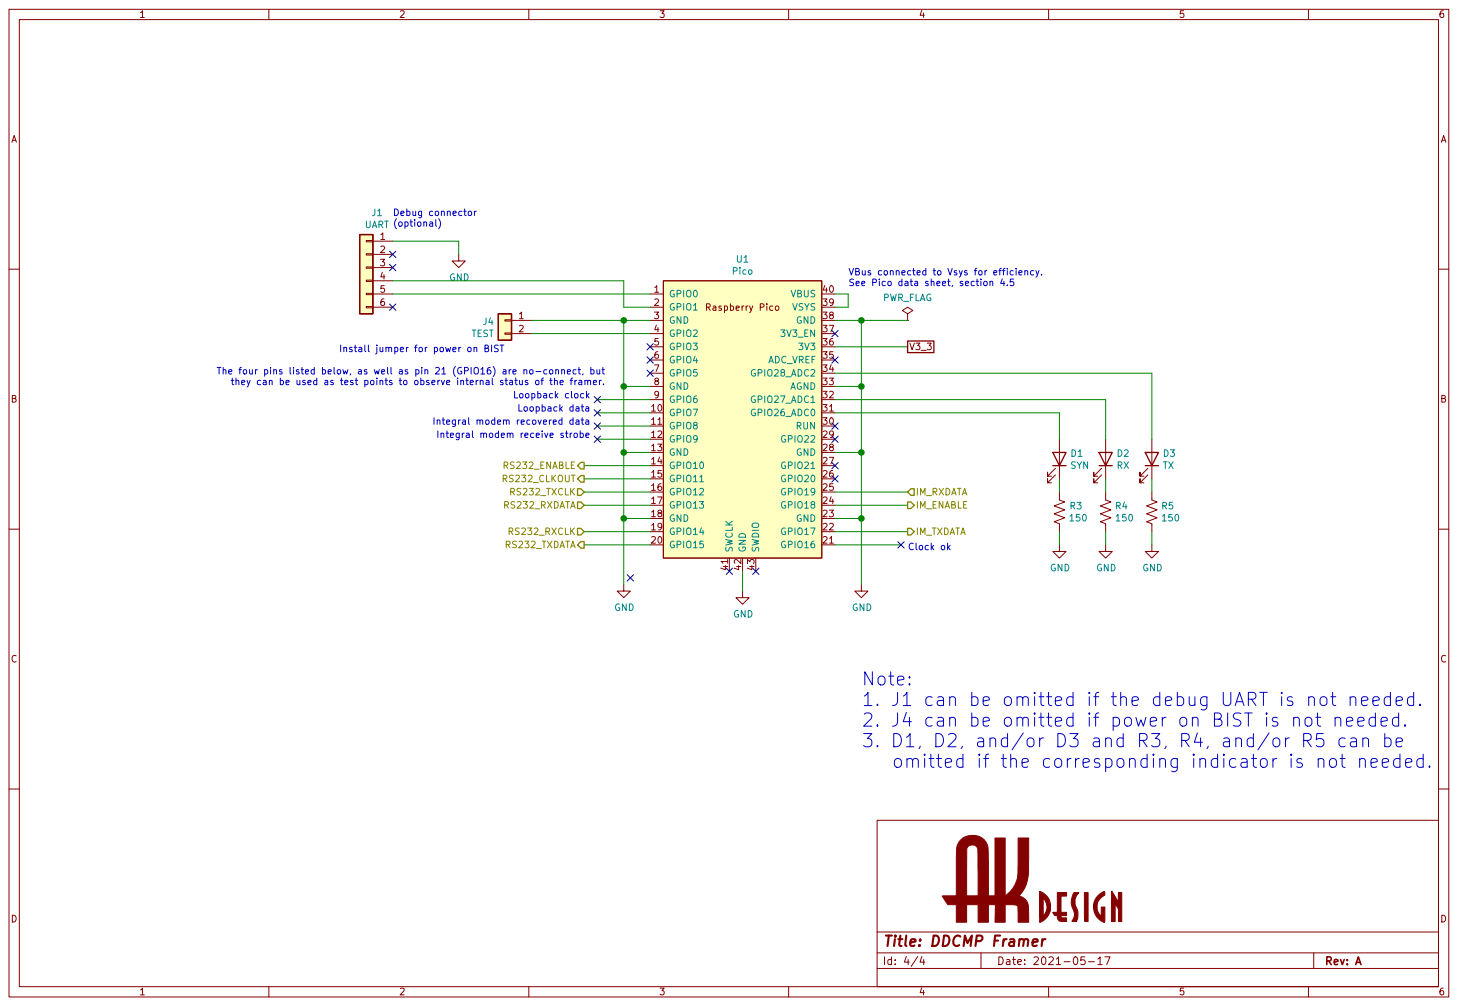
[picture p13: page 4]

Install jumper for power on BIST

The four pins listed below, as well as pin 21 (GPIO16) are no-connect, but
they can be used as test points to observe internal status of the framer.

Integral modem recovered data
Integral modem receive strobe

1. J1 can be omitted if the debug UART is not needed.
2. J4 can be omitted if power on BIST is not needed.
3. D1, D2, and/or D3 and R3, R4, and/or R5 can be
omitted if the corresponding indicator is not needed.

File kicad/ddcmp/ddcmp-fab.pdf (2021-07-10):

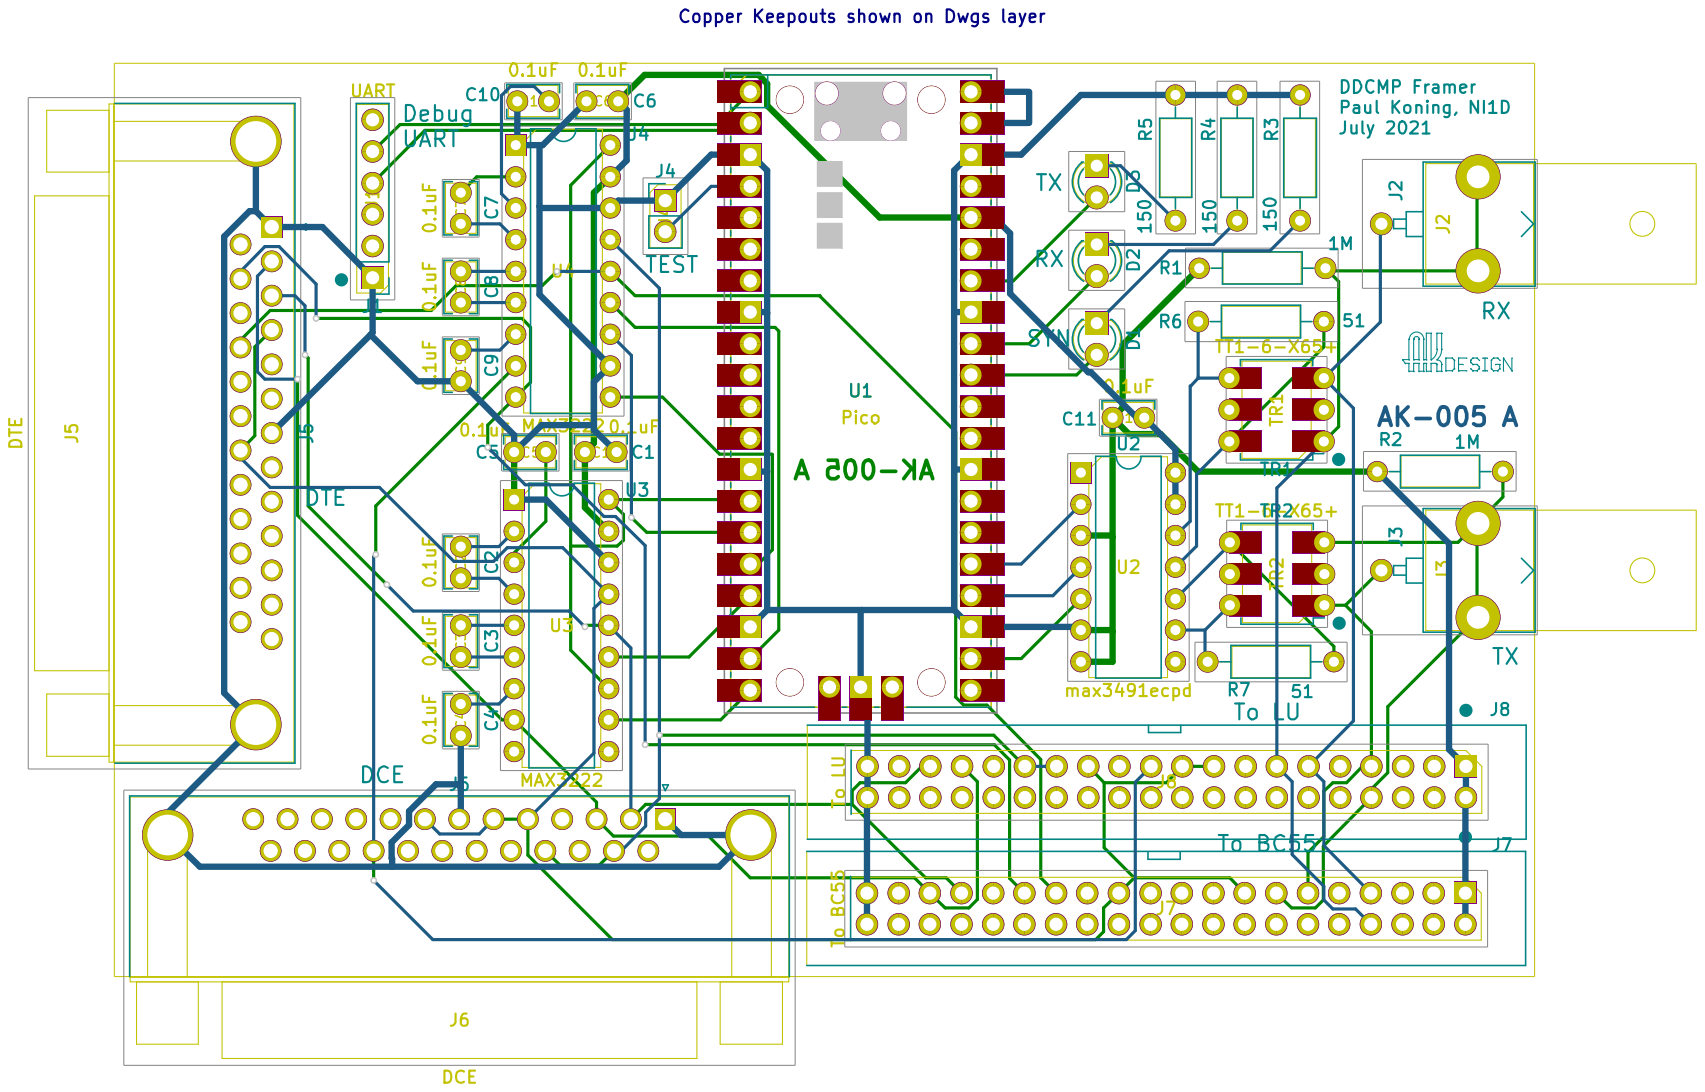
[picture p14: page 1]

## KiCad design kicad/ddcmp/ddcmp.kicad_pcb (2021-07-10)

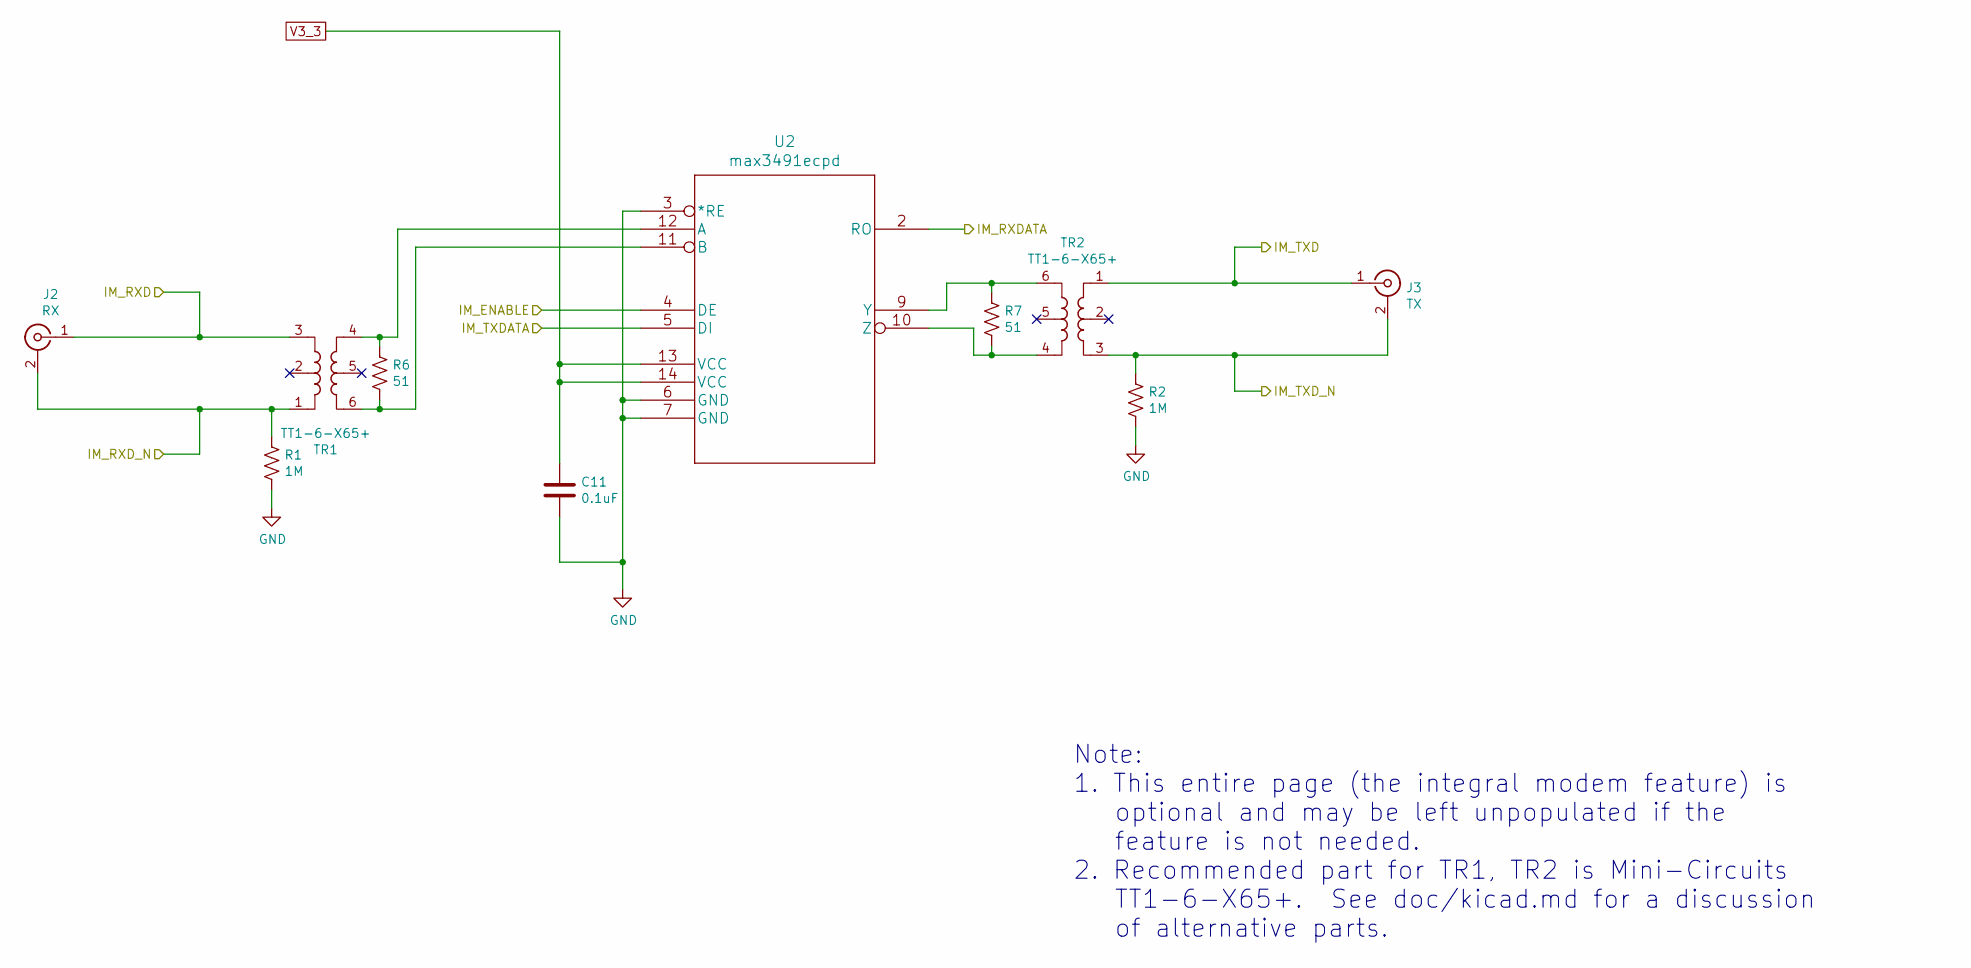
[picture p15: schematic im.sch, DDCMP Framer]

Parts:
C11: 0.1uF; C_Rect_L4.0mm_W2.5mm_P2.54mm; Digikey part 399-14010-1-ND
J2: RX; BNC_Molex_J_RA_PCB; Digikey part WM20430-ND
J3: TX; BNC_Molex_J_RA_PCB; Digikey part WM20430-ND
R1, R2: 1M; R_Axial_DIN0207_L6.3mm_D2.5mm_P10.16mm_Horizontal; Digikey part 1.0MQBK-ND
R6, R7: 51; R_Axial_DIN0207_L6.3mm_D2.5mm_P10.16mm_Horizontal; Digikey part 51QBK-ND
TR1, TR2: TT1-6-X65+; Mini-Circuits_CD637_X65
U2: max3491ecpd; DIP-14_W7.62mm; Digikey part MAX3491CPD+-ND

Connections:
/CPU/IM_ENABLE: U2.4 (DE); also elsewhere on the board
/CPU/IM_RXDATA: U2.2 (RO); also elsewhere on the board
/CPU/IM_TXDATA: U2.5 (DI); also elsewhere on the board
/Integral modem/IM_RXD: J2.1 (In), TR1.3; also elsewhere on the board
/Integral modem/IM_RXD_N: J2.2 (Ext), R1.1, TR1.1; also elsewhere on the board
/Integral modem/IM_TXD: J3.1 (In), TR2.1; also elsewhere on the board
/Integral modem/IM_TXD_N: J3.2 (Ext), R2.1, TR2.3; also elsewhere on the board
GND: C11.2, R1.2, R2.2, U2.3 (*RE), U2.6 (GND), U2.7 (GND); also elsewhere on the board
unnamed: R6.1, TR1.4, U2.12 (A)
unnamed: R6.2, TR1.6, U2.11 (B)
unnamed: R7.1, TR2.6, U2.9 (Y)
unnamed: R7.2, TR2.4, U2.10 (Z)
V3_3: C11.1, U2.13 (VCC), U2.14 (VCC); also elsewhere on the board

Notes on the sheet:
Note: 1. This entire page (the integral modem feature) is optional and may be left unpopulated if the feature is not needed. 2. Recommended part for TR1, TR2 is Mini-Circuits TT1-6-X65+. See doc/kicad.md for a discussion of alternative parts.

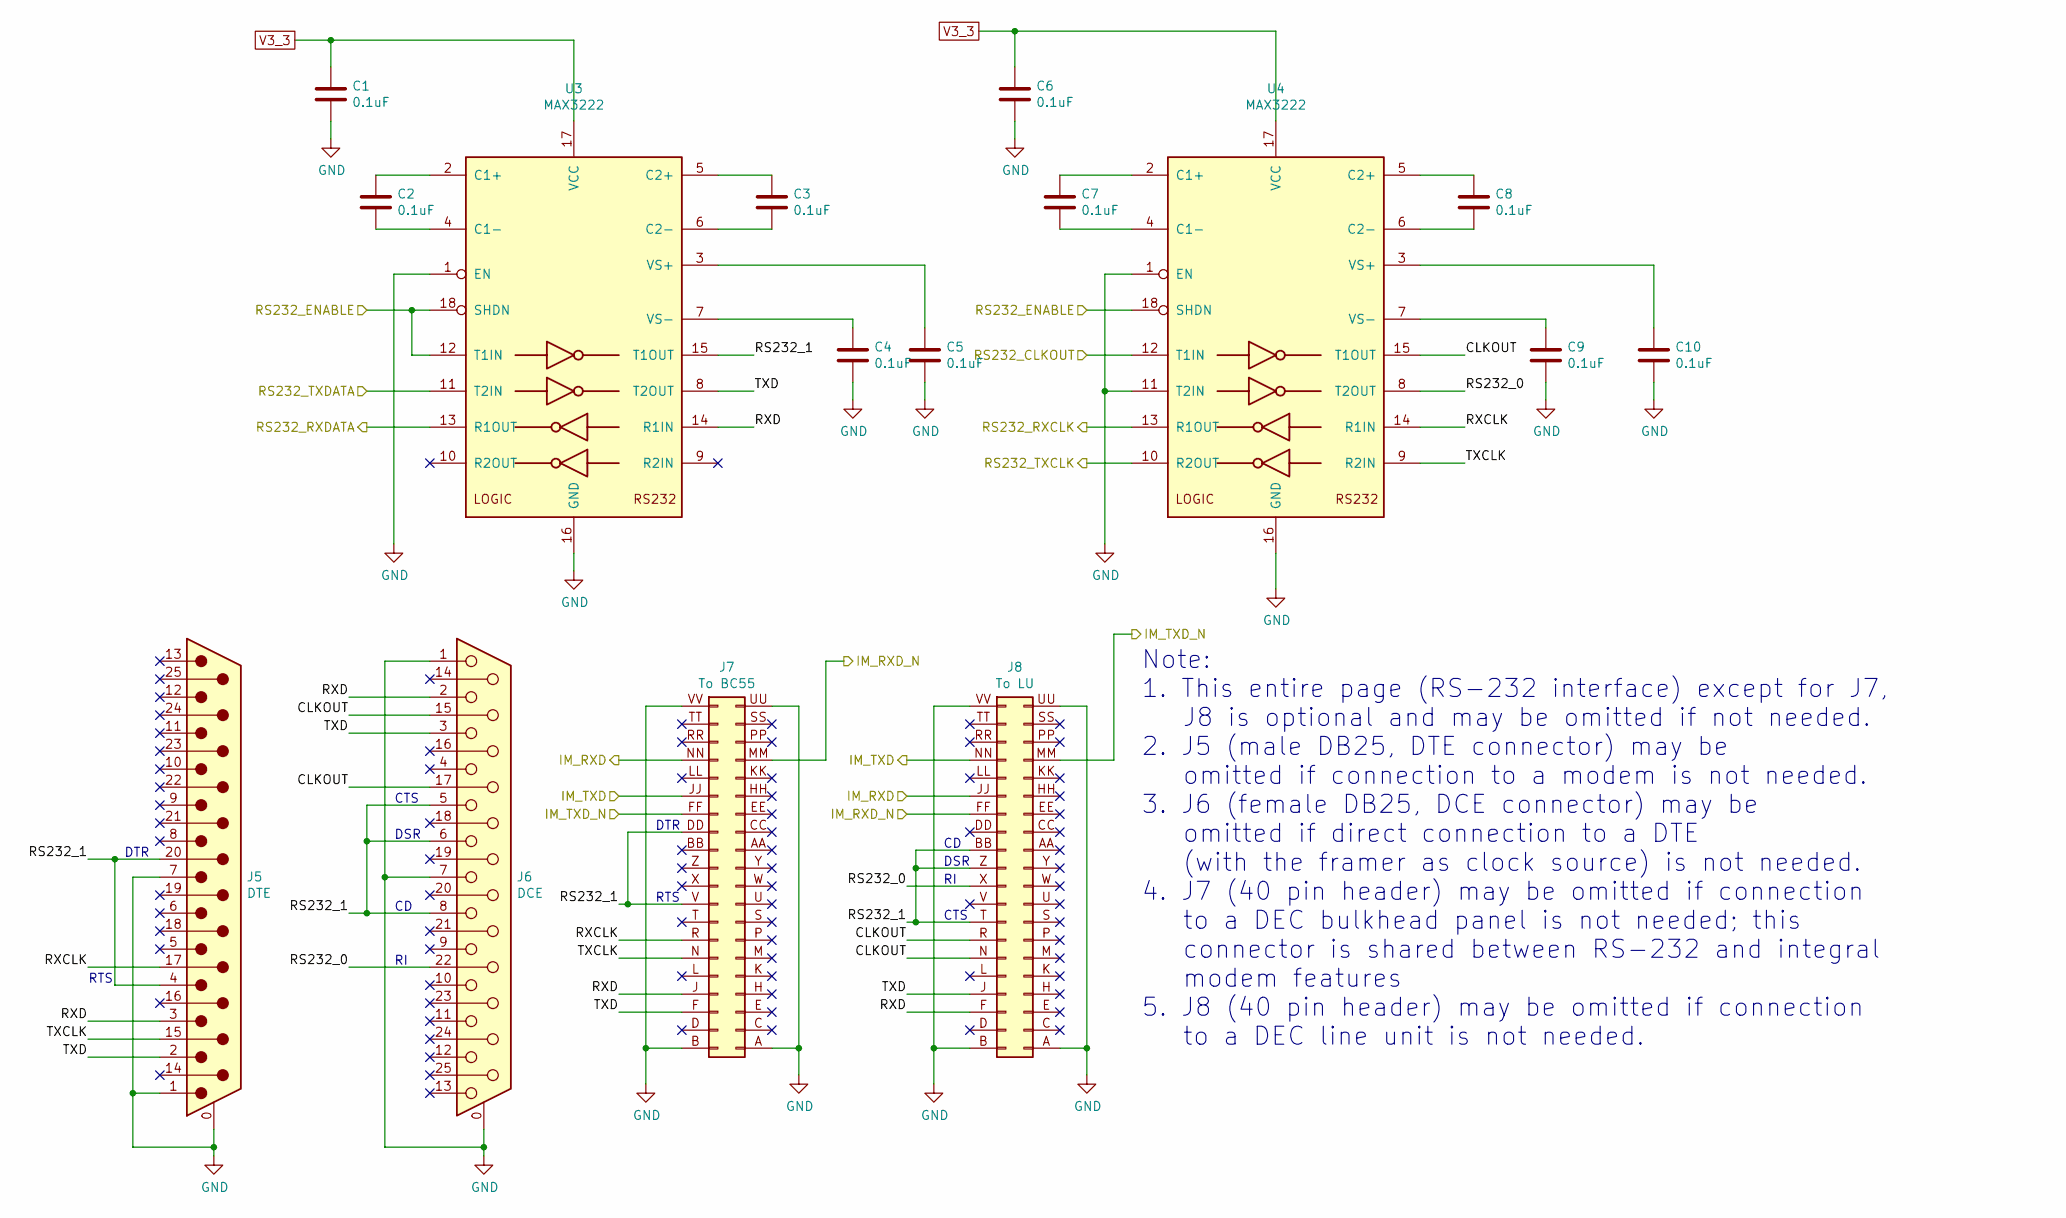
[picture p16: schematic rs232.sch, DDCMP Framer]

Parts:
C1, C2, C3, C4, C5, C6, C7, C8, C9, C10: 0.1uF; C_Rect_L4.0mm_W2.5mm_P2.54mm; Digikey part 399-14010-1-ND
J5: DTE; Amphenol_DB25M_PCB; Digikey part L717SDB25P1ACH4F-ND
J6: DCE; Amphenol_DB25F_PCB; Digikey part L77SDB25S1ACH3R-ND
J7: To BC55; Berg_40_pin_DEC_pinout; Digikey part 609-1779-ND
J8: To LU; Berg_40_pin_DEC_pinout; Digikey part 609-1779-ND
U3, U4: MAX3222; DIP-18_W7.62mm; Digikey part MAX3222ECPN+-ND

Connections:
/CPU/RS232_CLKOUT: U4.12 (T1IN); also elsewhere on the board
/CPU/RS232_ENABLE: U3.12 (T1IN), U3.18 (SHDN), U4.18 (SHDN); also elsewhere on the board
/CPU/RS232_RXCLK: U4.13 (R1OUT); also elsewhere on the board
/CPU/RS232_RXDATA: U3.13 (R1OUT); also elsewhere on the board
/CPU/RS232_TXCLK: U4.10 (R2OUT); also elsewhere on the board
/CPU/RS232_TXDATA: U3.11 (T2IN); also elsewhere on the board
/Integral modem/IM_RXD: J7.NN (Pin_7), J8.JJ (Pin_11); also elsewhere on the board
/Integral modem/IM_RXD_N: J7.MM (Pin_8), J8.FF (Pin_13); also elsewhere on the board
/Integral modem/IM_TXD: J7.JJ (Pin_11), J8.NN (Pin_7); also elsewhere on the board
/Integral modem/IM_TXD_N: J7.FF (Pin_13), J8.MM (Pin_8); also elsewhere on the board
/RS-232 I/O/CLKOUT: J6.15, J6.17, J8.N (Pin_29), J8.R (Pin_27), U4.15 (T1OUT)
/RS-232 I/O/RS232_0: J6.22, J8.X (Pin_21), U4.8 (T2OUT)
/RS-232 I/O/RS232_1: J5.4, J5.20, J6.5, J6.6, J6.8, J7.DD (Pin_15), J7.V (Pin_23), J8.BB (Pin_17), J8.T (Pin_25), J8.Z (Pin_19), U3.15 (T1OUT)
/RS-232 I/O/RXCLK: J5.17, J7.R (Pin_27), U4.14 (R1IN)
/RS-232 I/O/RXD: J5.3, J6.2, J7.J (Pin_33), J8.F (Pin_35), U3.14 (R1IN)
/RS-232 I/O/TXCLK: J5.15, J7.N (Pin_29), U4.9 (R2IN)
/RS-232 I/O/TXD: J5.2, J6.3, J7.F (Pin_35), J8.J (Pin_33), U3.8 (T2OUT)
GND: C1.2, C4.2, C5.2, C6.2, C9.2, C10.2, J5.0 (PAD), J5.1, J5.7, J6.0 (PAD), J6.1, J6.7, J7.A (Pin_40), J7.B (Pin_39), J7.UU (Pin_2), J7.VV (Pin_1), J8.A (Pin_40), J8.B (Pin_39), J8.UU (Pin_2), J8.VV (Pin_1), U3.1 (EN), U3.16 (GND), U4.1 (EN), U4.11 (T2IN), U4.16 (GND); also elsewhere on the board
unnamed: C2.1, U3.2 (C1+)
unnamed: C2.2, U3.4 (C1-)
unnamed: C3.1, U3.5 (C2+)
unnamed: C3.2, U3.6 (C2-)
unnamed: C4.1, U3.7 (VS-)
unnamed: C5.1, U3.3 (VS+)
unnamed: C7.1, U4.2 (C1+)
unnamed: C7.2, U4.4 (C1-)
unnamed: C8.1, U4.5 (C2+)
unnamed: C8.2, U4.6 (C2-)
unnamed: C9.1, U4.7 (VS-)
unnamed: C10.1, U4.3 (VS+)
V3_3: C1.1, C6.1, U3.17 (VCC), U4.17 (VCC); also elsewhere on the board

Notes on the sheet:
Note: 1. This entire page (RS-232 interface) except for J7, J8 is optional and may be omitted if not needed. 2. J5 (male DB25, DTE connector) may be omitted if connection to a modem is not needed. 3. J6 (female DB25, DCE connector) may be omitted if direct connection to a DTE (with the framer as cl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
RTS
DTR
DSR
CTS

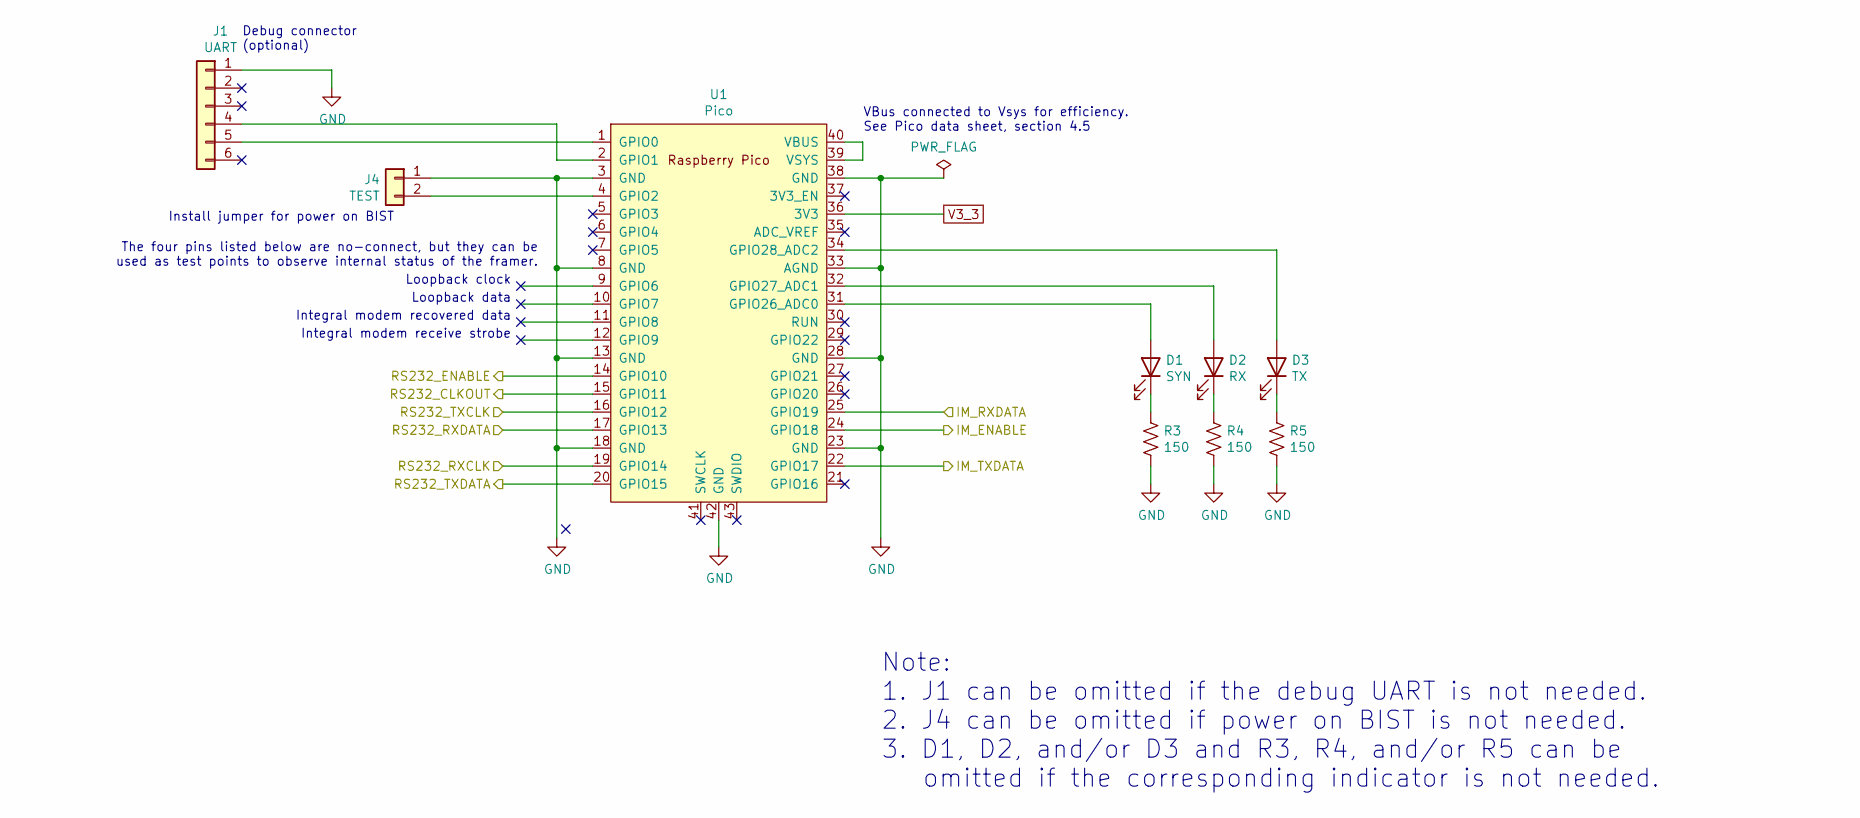
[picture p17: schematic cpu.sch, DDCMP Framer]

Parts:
D1: SYN; LED_D3.0mm; Digikey part 1497-1490-ND
D2: RX; LED_D3.0mm; Digikey part 1497-1492-ND
D3: TX; LED_D3.0mm; Digikey part 1497-1491-ND
J1: UART; Pin_Header_Straight_1x06_Pitch2.54mm; Digikey part 952-2269-ND
J4: TEST; Pin_Header_Straight_1x02_Pitch2.54mm; Digikey part 952-2261-ND
R3, R4, R5: 150; R_Axial_DIN0207_L6.3mm_D2.5mm_P10.16mm_Horizontal; Digikey part 150QBK-ND
U1: Pico; RPi_Pico_SMD_TH; Digikey part 2648-SC0915CT-ND

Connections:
/CPU/IM_ENABLE: U1.24 (GPIO18); also elsewhere on the board
/CPU/IM_RXDATA: U1.25 (GPIO19); also elsewhere on the board
/CPU/IM_TXDATA: U1.22 (GPIO17); also elsewhere on the board
/CPU/RS232_CLKOUT: U1.15 (GPIO11); also elsewhere on the board
/CPU/RS232_ENABLE: U1.14 (GPIO10); also elsewhere on the board
/CPU/RS232_RXCLK: U1.19 (GPIO14); also elsewhere on the board
/CPU/RS232_RXDATA: U1.17 (GPIO13); also elsewhere on the board
/CPU/RS232_TXCLK: U1.16 (GPIO12); also elsewhere on the board
/CPU/RS232_TXDATA: U1.20 (GPIO15); also elsewhere on the board
GND: J1.1, J4.1, R3.2, R4.2, R5.2, U1.3 (GND), U1.8 (GND), U1.13 (GND), U1.18 (GND), U1.23 (GND), U1.28 (GND), U1.33 (AGND), U1.38 (GND), U1.42 (GND); also elsewhere on the board
unnamed: D1.1 (K), R3.1
unnamed: D1.2 (A), U1.31 (GPIO26_ADC0)
unnamed: D2.1 (K), R4.1
unnamed: D2.2 (A), U1.32 (GPIO27_ADC1)
unnamed: D3.1 (K), R5.1
unnamed: D3.2 (A), U1.34 (GPIO28_ADC2)
unnamed: J1.4, U1.2 (GPIO1)
unnamed: J1.5, U1.1 (GPIO0)
unnamed: J4.2, U1.4 (GPIO2)
unnamed: U1.39 (VSYS), U1.40 (VBUS)
V3_3: U1.36 (3V3); also elsewhere on the board

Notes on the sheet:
Debug connector (optional)
VBus connected to Vsys for efficiency. See Pico data sheet, section 4.5
Loopback clock
Loopback data
Integral modem recovered data
Install jumper for power on BIST
Integral modem receive strobe
The four pins listed below are no-connect, but they can be used as test points to observe internal status of the framer.
Note: 1. J1 can be omitted if the debug UART is not needed. 2. J4 can be omitted if power on BIST is not needed. 3. D1, D2, and/or D3 and R3, R4, and/or R5 can be omitted if the corresponding indicator is not needed.

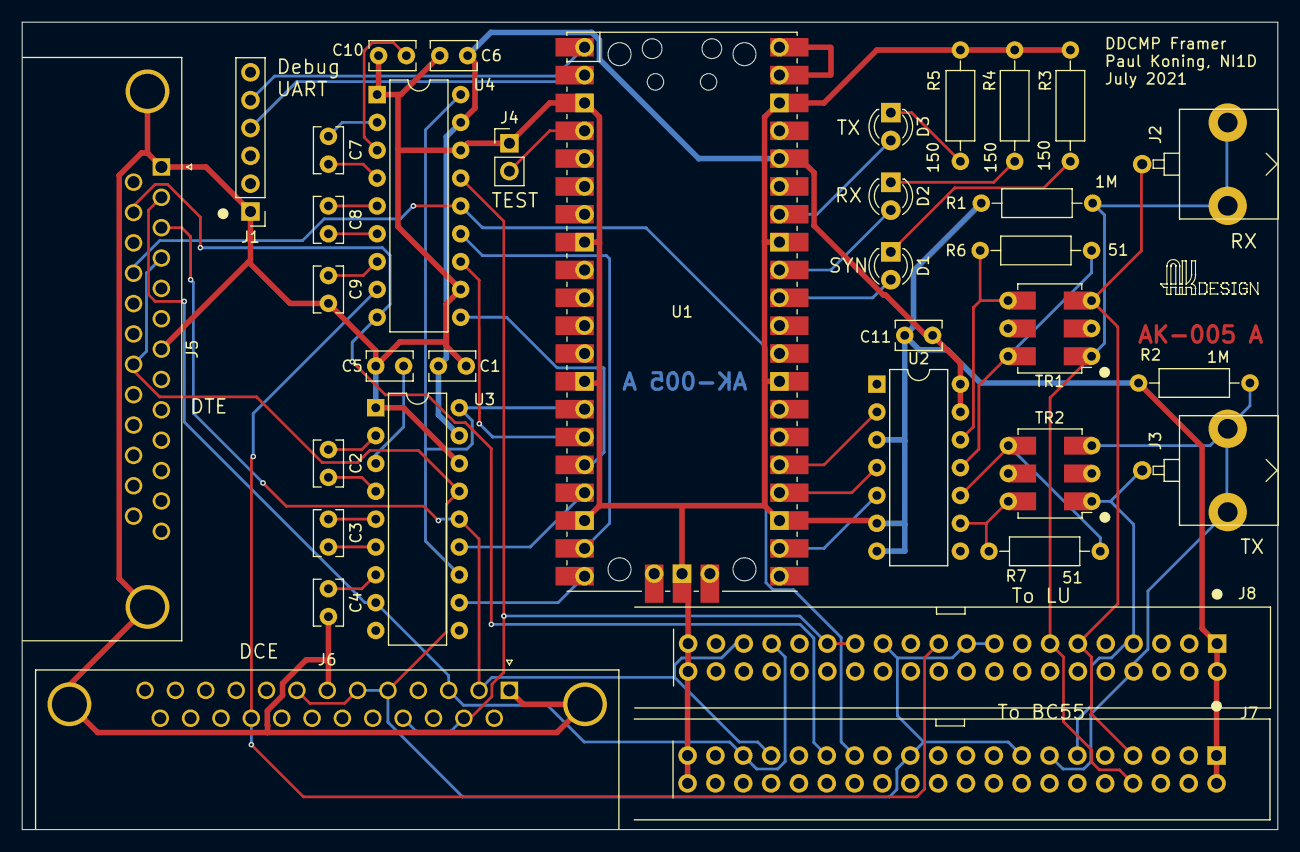
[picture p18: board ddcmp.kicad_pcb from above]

Board: 2 copper layers, 114.6 x 73.7 mm, 35 parts (0 on the bottom side), 48 nets.

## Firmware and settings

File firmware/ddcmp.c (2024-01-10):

// DDCMP Framer
//
// This is a USB-connected device that connects to DDCMP synchronous
// link devices, either RS-232 or DEC "integral modem" coax links,
// such as the DMC-11.
//
// Copyright (c) 2021, Paul Koning
//
// Please read file LICENSE for the license that applies to this project.


// Define this as 1 to send debug output to the debug UART, 0 to turn
// off UART use.
#define DEBUG 0

// Define this as 0 to turn off padding of frames going to the host.
// For maximal compatibility with various Ethernet drivers we normally
// pad frames so they are at least 60 bytes (Ethernet minimum, not
// counting CRC).  While USB does not need this, SIMH does.
//
// Note that padding is always allowed but never required on frames
// from host to framer.
//
// Padding has a noticeable impact on performance when dealing with
// rapid fire short frames (such as control frames).  For example, the
// unit test TestRaw.test_concat_ctl works at the full 1 Mb/s speed
// with padding off, but can only do 500 kb/s if padding is turned on.
#define PADRUNT 1

// Define this to 1 (default) for 8 bit transmit FIFO, 0 for 32 bit
// transmit FIFO.  For standard speeds, 8 bit FIFO is more than
// adequate.
#define TX8 1

#define __packed 
#define __aligned(x)

#include <string.h>

#include "bsp/board.h"
#include "tusb.h"

#include "ddcmp.pio.h"
#include <hardware/pio_instructions.h>
#include <hardware/timer.h>
#include "hardware/structs/sio.h"
#include "hardware/regs/sio.h"
#include <hardware/dma.h>
#include <pico/multicore.h>
#include <hardware/pll.h>
#include <hardware/clocks.h>
#include <pico/unique_id.h>

#define VERSION "DDCMP Framer V1.0"

#define MB asm volatile ("" : : : "memory")

#if PADRUNT
#define MINE(x) ((x) > 60) ? (x) : 60
#else
#define MINE(x) (x)
#endif

#if DEBUG
// Debugging, if enabled, uses the UART at the default pins (pin 1 and
// 2, GPIO 0 and GPIO 1).
#include <stdio.h>
#include <pico/stdio_uart.h>

#define DPRINTF printf
#else
#define DPRINTF(fmt...) // empty
#endif
#if DEBUG > 1
#define DDPRINTF DPRINTF
#else
#define DDPRINTF(fmt...) // empty
#endif

// PIO and state machine index assignments for the PIO state machines
// we use.  Note that the main transmit and receive state machines all
// have to be in the same PIO since IRQ, in spite of what the data
// sheet implies, is local to a given PIO and these state machines use
// IRQ to signal the receive machine to shift another bit.
#define RXPIO pio0
#define RXSM  0
#define IMBITPIO pio0
#define IMBITSM  1
#define TXPIO pio0
#define TXSM  2
#define FREQPIO  pio1
#define FREQSM   0
#define WDOGPIO  pio1
#define WDOGSM   1
// The two LED pulse stretcher SMs share the same program
#define BLINKPIO pio1
#define RXLEDSM  3
#define TXLEDSM  2

// Load addresses for these
uint16_t rxtop, txtop, imbittop, blinktop, freqtop;

// Jumps back to top
uint16_t rxsm_jmptop;
uint16_t blinksm_jmptop;
uint16_t freqsm_jmptop;

// Core 1 related state
volatile bool core1_active = false;
volatile int avg_period = 0;

// Receive (and more generally, the device) enabled state.
volatile bool rx_enabled = false;

// Last reported SYN status
bool syn_status = false;

// Selftest mode active
bool bist = false;

// Pin numbers (GPIOn numbers, to be precise)
// Clock/data pins
#define TXCLKIN 12      // Transmit clock input from modem
#define TXDATA  15      // Transmit data output
#define RXDATA  13      // RS232 receive data input
#define RXCLKIN 14      // Receive clock input from modem, must be RXDATA+1
#define CLKOUT  11      // RS232 clock output (RX/TX both) to DTE
#define IMTXDATA 17     // Integral modem transmit data output
#define IMRXDATA 19     // Integral modem receive data input
// Enable pins
#define RS232EN 10      // RS-232 output enable
#define IMEN    18      // Integral Modem enable
// Loopback test control
#define LOOPTEST 2      // Pull low to force power on selftest
// LED pin assignments
#define SYNLED   26     // In-sync indicator LED output
#define RXLED    27     // Packet received LED
#define ACTLED   25     // Device is active (RPico built-in LED)
#define TXLED    28     // Packet sent LED
// No-connect pins.  These are used when a signal needs to get from
// one state machine to another.  That applies to integral modem
// receive data (from demodulator), as well as to the loopback case.
// These pins are not connected to anything on the PC board, but they
// are enabled (both input and output circuits) so they have to be
// reserved for the purpose and configured as needed just like other
// pins.  IMSTROBE is an engineering test signal; the integral modem
// demodulator state machine generates a rising edge at the point
// where it samples the incoming waveform (nominally in the middle of
// the second half of the bit cell).
#define RXRECDATA 8     // Integral modem recovered receive bit stream
#define IMSTROBE  9     // Integral modem receive strobe (RXRECDATA + 1)
#define LCPIN     6     // Loopback clock pin
#define LDPIN     7     // Loopback data pin
#define CLOCKOK   16    // Bit clock ok (from watchdog state machine)

// These are pins we use as output; they are explicitly driven to 0 at
// initialization and ddcmp stop.
const uint8_t opins[] = {
    TXDATA,
    CLKOUT,
    IMTXDATA,
    RS232EN,
    IMEN,
    SYNLED,
    RXLED,
    ACTLED,
    TXLED,
    RXRECDATA,
    IMSTROBE,
    LCPIN,
    LDPIN,
    CLOCKOK
};

// DDCMP character codes
#define SOH 0201        // SOH - start of data message
#define ENQ 0005        // ENQ - start of control message
#define DLE 0220        // DLE - start of maintenance message
#define SYN 0226        // SYN - synchronization code
#define DEL 0377        // DEL - pad after message trailer

#define DC1 0021        // DC1 - used here for command/status, not DDCMP

#define SYN4 0x96969696U
#define RXLIMIT (1498 - 2) // Max received total frame size to host
#define RDMAX (RXLIMIT - 8 - 2) // Max receive DDCMP data length
#define TXLIMIT 1498    // Max transmit total frame size from host
#define TDMAX (TXLIMIT - 8) // Max transmit DDCMP data length
#define MAXLEN (RDMAX < TDMAX ? RDMAX : TDMAX) // Max DDCMP payload
#define RDATA (MAXLEN + 8 + 2) // Frame space in rings
#define ETH_HDR 14      // Length of Ethernet header
#define RBUF_OFF (ETH_HDR + 4) // Rx buffer offset to start of DDCMP frame
#define SYN_CNT 8       // Count of SYN bytes before tx frame start
#if TX8
#define SYN_CNT_V3 10   // Ditto, but in DMC11-AL V3 compatibility mode
#else
#define SYN_CNT_V3 12   // Ditto, but in DMC11-AL V3 compatibility mode
#endif

// Buffer counts.  The receive buffer count can be increased if
// desired, though there does not seem to be a good reason for doing
// so.  The transmit buffer count must NOT be increased (8 is the max)
// because there needs to be an available entry in the CPU0 -> CPU1
// FIFO for each transmit buffer.
#define RBUFS 8         // Number of buffers in receive ring
#define TBUFS 8         // Number of buffers in transmit ring

// Operating mode flags.  BIST is not normally requested from the
// host, but is generated internally if the LOOPTEST pin is pulled low
// at powerup.
#define INT_MODEM       1
#define RS232_LOCAL_CLK 2
#define INT_LOOPBACK    4
#define BIST            8
#define SPLIT           16
#define DDCMP3          32  // DDCMP V3.03 (DMC-11) compatibility
#define RAW_WAVEFORM    64  // Integral modem test, send raw waveforms

// DDCMP framing state machine state codes
enum ddcmp_state
{
    PKT_START,          // Looking for start of packet
    HEADER,             // Processing header
    PAYLOAD,            // Processing payload
    DEL1,               // Checking for optional trailing DEL
    FLUSH               // Flushing receive FIFO for resync
};

// DDCMP frame buffer status codes
enum ddcmp_status
{
    DDCMP_OK,           // Good packet
    DDCMP_HCRC,         // Header CRC error
    DDCMP_CRC,          // Payload CRC error
    DDCMP_LONG,         // Payload too long
    DDCMP_LOC,          // Loss of carrier in mid-frame
    BUF_EMPTY           // Buffer waiting to be filled
};

// DDCMP frame buffer layout (framer to host)
struct ddcmp_rxframe
{
    uint8_t bufhdr[ETH_HDR]; // room for "Ethernet" header
    uint16_t data_len;      // DDCMP payload length
    volatile uint16_t stat; // Status (ddcmp_status code)
    uint8_t data[RDATA];    // DDCMP frame data (header + payload)
};

// Receive ring
struct ddcmp_rxframe rbuf_ring[RBUFS];
volatile int rbuf_empty = 0;
volatile int rbuf_fill = 0;

// DDCMP frame buffer layout (host to framer, transmit ring entry)
struct ddcmp_txframe
{
    volatile uint32_t data_len; // Total length (including SYN and DEL)
    uint8_t *data_start;    // Starting address (syn or syn + 2 or 4)
    uint8_t syn[SYN_CNT_V3]; // SYN bytes before frame start
    uint8_t data[RDATA];    // DDCMP frame data (header + payload)
    uint8_t del;            // DEL after the CRC
};

// Transmit ring
struct ddcmp_txframe tbuf_ring[TBUFS];
volatile int tbuf_empty = 0;
volatile int tbuf_fill = 0;

// Set to true in the transmit handler if it has no room for another
// transmit, checked in the main loop to re-request the transmit
// buffer from USB if the count now permits transmitting more.
volatile bool tx_full = false;

// Set to true if we're in DMC11 mode using integral modem, i.e.,
// talking to a DMC11-AL.
bool dmc_syn_al = false;

// Set to true if we're in DMC11 mode, any link type.
bool dmc = false;

// True if we're in raw waveform mode.
bool raw_wave = false;

// DMA channel number
int txdma;
// DMA channel mask
uint txdmask;
// DMA channel CSR pointer
volatile dma_channel_hw_t *txcsr;

// Default buffer header (Ethernet header) for messages from framer to
// host.  The host interface address is aa-00-03-xx-yy-zz where the
// last 24 bits are random values generated from the board unique ID.
// The framer appears as an Ethernet device on that LAN with address
// one larger than the host interface address.
static uint8_t default_hdr[RBUF_OFF] = {
    0xaa, 0x00, 0x03, 0x00, 0x00, 0x00,         // Dest:   aa-00-03-xx-yy-zz
    0xaa, 0x00, 0x03, 0x00, 0x00, 0x00,         // Source
    0x60, 0x06,                                 // Prot:   60-06 (customer)
    0, 0,                                       // Payload length
    BUF_EMPTY, 0x00                             // Status
};

// This is the USB Ethernet interface address.
//
// PLEASE NOTE: In the standard tinyusb library this is declared as
// "extern const uint8_t [6]" which we can't accept because the low
// order bits have to be set at initialization time.  You will need to
// edit src/class/net/net_device.h to remove the "const" from that
// declaration, otherwise the compiler will complain.
uint8_t tud_network_mac_address[6] = {
    0xaa, 0x00, 0x03, 0x00, 0x00, 0x00         // ifaddr: aa-00-03-xx-yy-zz
};

// Command message.  This starts like a data message, except that the
// header byte is DC1 (0x11) rather than one of the three DDCMP start
// of header codes.
struct command_msg_t
{
    uint8_t dc1;
    uint8_t cmd;
    uint16_t mflags __attribute__ ((packed));
    uint32_t speed __attribute__ ((packed));
    uint32_t txspeed __attribute__ ((packed)); // Optional: split speed
};

enum ddcmp_action
{
    REQ_STATUS,         // Get device status
    REQ_START,          // Start DDCMP engine
    REQ_STOP,           // Stop DDCMP engine
    REQ_RAWTX           // Raw transmit
};

// Status message.  This starts like a data message, except that the
// header byte is DC1 (0x11) rather than one of the three DDCMP start
// of header codes.
// Note that things must be kept naturally aligned to avoid padding.
struct status_msg_t
{
    uint8_t bufhdr[ETH_HDR];        // room for "Ethernet" header
    uint16_t data_len;              // Length of Ethernet payload
    uint16_t stat;                  // Status (ddcmp_status code)
    uint8_t dc1;
    uint8_t on;                     // "on" flags
    uint16_t mflags;
    uint16_t sdusize;               // Max DDCMP frame payload
    uint32_t speed;
    uint32_t txspeed;
    uint32_t rxframes;
    uint32_t rxbytes;
    uint32_t txframes;
    uint32_t txbytes;
    uint32_t hcrc_err;
    uint32_t crc_err;
    uint32_t len_err;
    uint32_t nobuf_err;
    uint32_t last_cmd_sts;          // Response code from last command
    uint32_t freq;                  // Measured frequency
    char version[sizeof (VERSION)];
};

#define ON_ACT 1
#define ON_SYN 2
#define ON_CLKOK 4

enum last_cmd_status_t
{
    CMD_OK = 0,             // Command was accepted
    CMD_BAD_MSG,            // Command message too short
    CMD_UNKNOWN,            // Unknown command code
    CMD_ACTIVE,             // Start command when already active
    CMD_BAD_SPEED,          // Speed is out of range
    TX_BAD_LENGTH,          // Transmit frame bad length
    TX_OFF,                 // Transmit request when device is off
    CMD_BAD_MODE,           // Invalid start mode flags
    TX_WHEN_RAW,            // Transmit during raw waveform mode
};

struct status_msg_t status_msg;
bool send_status = false;

// 8 bits at a time CRC table, from PyDECnet crc.py
// crc16 polynomial x^16 + x^15 + x^2 + 1 (0x8005) CCITT LSB 
static const uint16_t crc16_table[256] = {
    0x0000, 0xc0c1, 0xc181, 0x0140, 0xc301, 0x03c0, 0x0280, 0xc241,
    0xc601, 0x06c0, 0x0780, 0xc741, 0x0500, 0xc5c1, 0xc481, 0x0440,
    0xcc01, 0x0cc0, 0x0d80, 0xcd41, 0x0f00, 0xcfc1, 0xce81, 0x0e40,
    0x0a00, 0xcac1, 0xcb81, 0x0b40, 0xc901, 0x09c0, 0x0880, 0xc841,
    0xd801, 0x18c0, 0x1980, 0xd941, 0x1b00, 0xdbc1, 0xda81, 0x1a40,
    0x1e00, 0xdec1, 0xdf81, 0x1f40, 0xdd01, 0x1dc0, 0x1c80, 0xdc41,
    0x1400, 0xd4c1, 0xd581, 0x1540, 0xd701, 0x17c0, 0x1680, 0xd641,
    0xd201, 0x12c0, 0x1380, 0xd341, 0x1100, 0xd1c1, 0xd081, 0x1040,
    0xf001, 0x30c0, 0x3180, 0xf141, 0x3300, 0xf3c1, 0xf281, 0x3240,
    0x3600, 0xf6c1, 0xf781, 0x3740, 0xf501, 0x35c0, 0x3480, 0xf441,
    0x3c00, 0xfcc1, 0xfd81, 0x3d40, 0xff01, 0x3fc0, 0x3e80, 0xfe41,
    0xfa01, 0x3ac0, 0x3b80, 0xfb41, 0x3900, 0xf9c1, 0xf881, 0x3840,
    0x2800, 0xe8c1, 0xe981, 0x2940, 0xeb01, 0x2bc0, 0x2a80, 0xea41,
    0xee01, 0x2ec0, 0x2f80, 0xef41, 0x2d00, 0xedc1, 0xec81, 0x2c40,
    0xe401, 0x24c0, 0x2580, 0xe541, 0x2700, 0xe7c1, 0xe681, 0x2640,
    0x2200, 0xe2c1, 0xe381, 0x2340, 0xe101, 0x21c0, 0x2080, 0xe041,
    0xa001, 0x60c0, 0x6180, 0xa141, 0x6300, 0xa3c1, 0xa281, 0x6240,
    0x6600, 0xa6c1, 0xa781, 0x6740, 0xa501, 0x65c0, 0x6480, 0xa441,
    0x6c00, 0xacc1, 0xad81, 0x6d40, 0xaf01, 0x6fc0, 0x6e80, 0xae41,
    0xaa01, 0x6ac0, 0x6b80, 0xab41, 0x6900, 0xa9c1, 0xa881, 0x6840,
    0x7800, 0xb8c1, 0xb981, 0x7940, 0xbb01, 0x7bc0, 0x7a80, 0xba41,
    0xbe01, 0x7ec0, 0x7f80, 0xbf41, 0x7d00, 0xbdc1, 0xbc81, 0x7c40,
    0xb401, 0x74c0, 0x7580, 0xb541, 0x7700, 0xb7c1, 0xb681, 0x7640,
    0x7200, 0xb2c1, 0xb381, 0x7340, 0xb101, 0x71c0, 0x7080, 0xb041,
    0x5000, 0x90c1, 0x9181, 0x5140, 0x9301, 0x53c0, 0x5280, 0x9241,
    0x9601, 0x56c0, 0x5780, 0x9741, 0x5500, 0x95c1, 0x9481, 0x5440,
    0x9c01, 0x5cc0, 0x5d80, 0x9d41, 0x5f00, 0x9fc1, 0x9e81, 0x5e40,
    0x5a00, 0x9ac1, 0x9b81, 0x5b40, 0x9901, 0x59c0, 0x5880, 0x9841,
    0x8801, 0x48c0, 0x4980, 0x8941, 0x4b00, 0x8bc1, 0x8a81, 0x4a40,
    0x4e00, 0x8ec1, 0x8f81, 0x4f40, 0x8d01, 0x4dc0, 0x4c80, 0x8c41,
    0x4400, 0x84c1, 0x8581, 0x4540, 0x8701, 0x47c0, 0x4680, 0x8641,
    0x8201, 0x42c0, 0x4380, 0x8341, 0x4100, 0x81c1, 0x8081, 0x4040
};

static inline uint16_t update_crc (uint16_t crc, uint8_t b)
{
    crc = (crc >> 8) ^ crc16_table[b ^ (crc & 0xff)];
    return crc;
}

// Set the PIO receive state machine back to its start to make it go
// back to searching for SYN.
static inline void syn_search (void)
{
    pio_sm_exec (RXPIO, RXSM, rxsm_jmptop);
}

static inline void rxblink (void)
{
    pio_sm_exec (BLINKPIO, RXLEDSM, blinksm_jmptop);
}

static inline void txblink (void)
{
    pio_sm_exec (BLINKPIO, TXLEDSM, blinksm_jmptop);
}

static inline void buf_done (enum ddcmp_status stat)
{
    DDPRINTF ("buffer %d (%d) done, status %d\n", rbuf_fill, rbuf_empty, stat);
    MB;
    rbuf_ring[rbuf_fill].stat = stat;
    rbuf_fill = (rbuf_fill + 1) % RBUFS;
    rxblink ();
}

// For some reason these aren't standard functions.
static void gpio_set_drive (int gpio, int strength)
{
    // Set drive strength bits
    hw_write_masked(&padsbank0_hw->io[gpio],
                    strength << PADS_BANK0_GPIO0_DRIVE_LSB,
                    PADS_BANK0_GPIO0_DRIVE_BITS);
}

static void gpio_set_slew (int gpio, int fast)
{
    // Set slew rate bit
    hw_write_masked(&padsbank0_hw->io[gpio],
                    fast << PADS_BANK0_GPIO0_SLEWFAST_LSB,
                    PADS_BANK0_GPIO0_SLEWFAST_BITS);
}
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
int main ()
{
    union 
    {
        pico_unique_board_id_t uid;
        uint32_t id32[2];
    } id;
    uint32_t id24;
    int i;
    
    // Start by changing the system clock to 120 MHz, which is an
    // integral multiple of the fast line speeds we want to support.
    // That way we can support the exact nominal values rather than
    // having to choose between jitter (due to fractional dividers) or
    // rates that are not actually what was asked for.
    // Various code snippets here were lifted from the Pico SDK.

    // 1. Set the sys clock to use the ref clock
    // CLK SYS = CLK_REF.
    uint clk_ref_freq = clock_get_hz (clk_ref);
    clock_configure (clk_sys,
                     CLOCKS_CLK_SYS_CTRL_SRC_VALUE_CLK_REF,
                     0,
                     clk_ref_freq,
                     clk_ref_freq);

    // 2. Set the sys PLL to 120 MHz.  This waits for PLL lock.
    pll_init (pll_sys, 1, 1440 * MHZ, 6, 2);

    // 3. Set sys clock back to use the PLL
    // CLK SYS = PLL SYS (120 MHz) / 1 = 120 MHz
    clock_configure (clk_sys,
                     CLOCKS_CLK_SYS_CTRL_SRC_VALUE_CLKSRC_CLK_SYS_AUX,
                     CLOCKS_CLK_SYS_CTRL_AUXSRC_VALUE_CLKSRC_PLL_SYS,
                     120 * MHZ,
                     120 * MHZ);

    // 4. Peri clock uses sys clock.  Just call clock_configure to set
    // it up, though it's normally already set that way and all that's
    // changing is the declared frequency.
    clock_configure (clk_peri,
                     0,
                     CLOCKS_CLK_PERI_CTRL_AUXSRC_VALUE_CLK_SYS,
                     120 * MHZ,
                     120 * MHZ);

    // Get unique ID, use it to make up Ethernet addresses.  The
    // interface address is forced to be even, the framer address is
    // one higher.
    pico_get_unique_board_id (&id.uid);
    id24 = (id.id32[0] ^ id.id32[1]) & 0xfffffe;
    default_hdr[3] = (id24 >> 16) & 0xff;
    default_hdr[4] = (id24 >>  8) & 0xff;
    default_hdr[5] = (id24 >>  0) & 0xff;
    id24++;
    default_hdr[6 + 3] = (id24 >> 16) & 0xff;
    default_hdr[6 + 4] = (id24 >>  8) & 0xff;
    default_hdr[6 + 5] = (id24 >>  0) & 0xff;
    memcpy (tud_network_mac_address, default_hdr, 6);
    
#if DEBUG
    // Initialize stdio and the UART.  Note this has to be done after
    // the manipulation of the system clock speeds.
    stdio_init_all ();
#endif
    DPRINTF ("\n\nInitializing DDCMP framer\n");
    DPRINTF (VERSION "\n");
    DPRINTF ("Max packet length: %d\n", MAXLEN);
    DPRINTF ("Interface address: ");
    for (i = 0; i < 5; i++)
        DPRINTF ("%02X-", default_hdr[i]);
    DPRINTF ("%02X\n", default_hdr[5]);
    
    init_once ();

    // See if selftest is requested (TEST pin pulled down)
    if (gpio_get (LOOPTEST) == 0)
    {
        DPRINTF ("Selftest requested\n");
        DPRINTF ("Starting integral modem BIST, internal loopback, 1 Mbps\n");
        // We use the integral modem (since that's the most complex
        // case) at max standard speed (1 Mb/s).
        start_ddcmp (BIST | INT_LOOPBACK | INT_MODEM, 1000000, 1000000);
    }
    
    /* initialize TinyUSB */
    DPRINTF ("Initializing USB\n");
    tusb_init();
    send_status = true;

    DPRINTF ("Entering main loop\n");
    while (1) 
    {
        if (bist)
        {
            send_bist_data ();
        }
        if (status_msg.on & ON_ACT)
        {
            // Framer is on, see if we need to update host with new
            // SYN status.
            if (gpio_get (SYNLED))
            {
                if (!syn_status)
                {
                    send_status = true;
                    DPRINTF ("Status request, SYN now true\n");
                }
            }
            else if (syn_status)
            {
                send_status = true;
                DPRINTF ("Status request, SYN now false\n");
            }
        }
        tud_task();
        handle_rbuf ();
        handle_tdone ();
    }
    // UNREACHABLE:
    return 0;
}

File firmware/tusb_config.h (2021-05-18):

/*
 * The MIT License (MIT)
 *
 * Copyright (c) 2019 Ha Thach (tinyusb.org)
 *
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
 */

#ifndef _TUSB_CONFIG_H_
#define _TUSB_CONFIG_H_

#ifdef __cplusplus
 extern "C" {
#endif

//--------------------------------------------------------------------
// COMMON CONFIGURATION
//--------------------------------------------------------------------

#define CFG_TUSB_MCU OPT_MCU_RP2040
#define CFG_TUSB_OS OPT_OS_PICO

     
// defined by board.mk
#ifndef CFG_TUSB_MCU
  #error CFG_TUSB_MCU must be defined
#endif

// RHPort number used for device can be defined by board.mk, default to port 0
#ifndef BOARD_DEVICE_RHPORT_NUM
  #define BOARD_DEVICE_RHPORT_NUM     0
#endif

// RHPort max operational speed can defined by board.mk
// Default to Highspeed for MCU with internal HighSpeed PHY (can be port specific), otherwise FullSpeed
#ifndef BOARD_DEVICE_RHPORT_SPEED
  #if (CFG_TUSB_MCU == OPT_MCU_LPC18XX || CFG_TUSB_MCU == OPT_MCU_LPC43XX || CFG_TUSB_MCU == OPT_MCU_MIMXRT10XX || \
       CFG_TUSB_MCU == OPT_MCU_NUC505  || CFG_TUSB_MCU == OPT_MCU_CXD56)
    #define BOARD_DEVICE_RHPORT_SPEED   OPT_MODE_HIGH_SPEED
  #else
    #define BOARD_DEVICE_RHPORT_SPEED   OPT_MODE_FULL_SPEED
  #endif
#endif

// Device mode with rhport and speed defined by board.mk
#if   BOARD_DEVICE_RHPORT_NUM == 0
  #define CFG_TUSB_RHPORT0_MODE     (OPT_MODE_DEVICE | BOARD_DEVICE_RHPORT_SPEED)
#elif BOARD_DEVICE_RHPORT_NUM == 1
  #define CFG_TUSB_RHPORT1_MODE     (OPT_MODE_DEVICE | BOARD_DEVICE_RHPORT_SPEED)
#else
  #error "Incorrect RHPort configuration"
#endif

// CFG_TUSB_DEBUG is defined by compiler in DEBUG build
// #define CFG_TUSB_DEBUG           0

/* USB DMA on some MCUs can only access a specific SRAM region with restriction on alignment.
 * Tinyusb use follows macros to declare transferring memory so that they can be put
 * into those specific section.
 * e.g
 * - CFG_TUSB_MEM SECTION : __attribute__ (( section(".usb_ram") ))
 * - CFG_TUSB_MEM_ALIGN   : __attribute__ ((aligned(4)))
 */
#ifndef CFG_TUSB_MEM_SECTION
#define CFG_TUSB_MEM_SECTION
#endif

#ifndef CFG_TUSB_MEM_ALIGN
#define CFG_TUSB_MEM_ALIGN          __attribute__ ((aligned(4)))
#endif

//--------------------------------------------------------------------
// DEVICE CONFIGURATION
//--------------------------------------------------------------------

#ifndef CFG_TUD_ENDPOINT0_SIZE
#define CFG_TUD_ENDPOINT0_SIZE    64
#endif

//------------- CLASS -------------//
#define CFG_TUD_CDC               0
#define CFG_TUD_MSC               0
#define CFG_TUD_HID               0
#define CFG_TUD_MIDI              0
#define CFG_TUD_VENDOR            0
#define CFG_TUD_NET               1

#ifdef __cplusplus
 }
#endif

#endif /* _TUSB_CONFIG_H_ */

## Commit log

2021-05-18 Initial commit
    This is not yet complete and not working. The board layout hasn't
    started yet.
    [CD542.step, Pico-R3.step, cpu.sch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]
2021-05-18 Finish the connector hookups, to be verified carefully against DMR-11 schematics.
    [cpu.sch, ddcmp.kicad_pcb, ddcmp.sch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]
2021-05-21 Complete schematic, PCB layout, and matching code. Needs testing.
    [731000105.step, 75869_y07_asm.step, cpu.sch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]
2021-05-26 Schematics tweaks, better 3d model for RPico.
    [Raspberry_Pico.step, ddcmp.kicad_pcb]
2021-05-26 Bugfixes. This version now reliably runs built-in self test at full 1 Mb/s line speed.
    [ddcmp.c]
2021-05-31 Bugfixes; add frequency measurement, raw transmit.
    [CD542.step]
2021-05-31 Schematic and PCB modeling tweaks.
    [CD637.step, cpu.sch, ddcmp.kicad_pcb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]
2021-06-03 Add Pico model from Nicolò Carandini
    For the original see https://github.com/ncarandini/KiCad-RP-Pico
2021-06-08 Schematics and 3d model cleanups; first drafts of a lot of documentation.
    [BERG_blue_40pin.step, LED_D3.0mm_green.step, LED_D3.0mm_red.step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]
2021-06-08 Add missing solder paste for Raspberry Pico footprint.
    [ddcmp.kicad_pcb]
2021-06-10 Small schematics changes. Rewrite the integral modem receive demodulator state machine.
    [cpu.sch, im.sch, rs232.sch]
2021-07-07 Documentation improvements, small schematic fixes. Also firmware improvements, particularly clock rate accuracy.
    [Raspberry_Pico.step, ddcmp.kicad_pcb, ddcmp.sch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]
2021-07-10 Small PCB tweaks. This version appears to be ready for fab.
    [ddcmp.kicad_pcb]
2021-07-11 Fix counters; in non-DEBUG mode some counters would not be seen due to counting them in CPU 1. Now they are counted as part of completed receive buffer handling in CPU 0.
    [ddcmp.c]
2021-07-11 A better fix to the previous issue. It wasn't caching; it's a missing memory barrier causing CPU 1 to keep some state in registers that needs to go to memory for CPU 0 to see it.
    [ddcmp.c]
2021-07-15 Do transmit DMA control (initiate DMA, handle completion) in the CPU 1 polling loop rather than by CPU 0 interrupts. This makes the code substantially simpler since the main control code no longer ha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
    [ddcmp.c]
2021-08-23 Bugfixes in firmware, add status report on SYN status change. Update documentation. Add links for OSHPark shared PCB layout and Digikey shared BOM.
    [ddcmp.c]
2021-09-16 1. Change transmit frame format to include a space for header CRC, so SIMH standard frame formatting works unchanged. The HCRC is still generated, though. 2. Change MAC addresses to be random AA-00-0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
2021-10-17 1. Add bit clock monitor and abort frame reception if clock is lost. 2. Make frequency measurement better for integral modem case. 3. New test mode: raw waveform (for integral modem).
    [cpu.sch]
2021-12-25 Fix description of test point on page 4 of the schematic.
    [cpu.sch]
2021-12-31 Clarify the way framer MAC addresses are constructed.
2024-01-10 Fix tud_network_can_xmit calls to add missing argument. An error not detected previously, or an API change? Not clear.
    [ddcmp.c]

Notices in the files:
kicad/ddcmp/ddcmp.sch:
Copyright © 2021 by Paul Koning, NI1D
